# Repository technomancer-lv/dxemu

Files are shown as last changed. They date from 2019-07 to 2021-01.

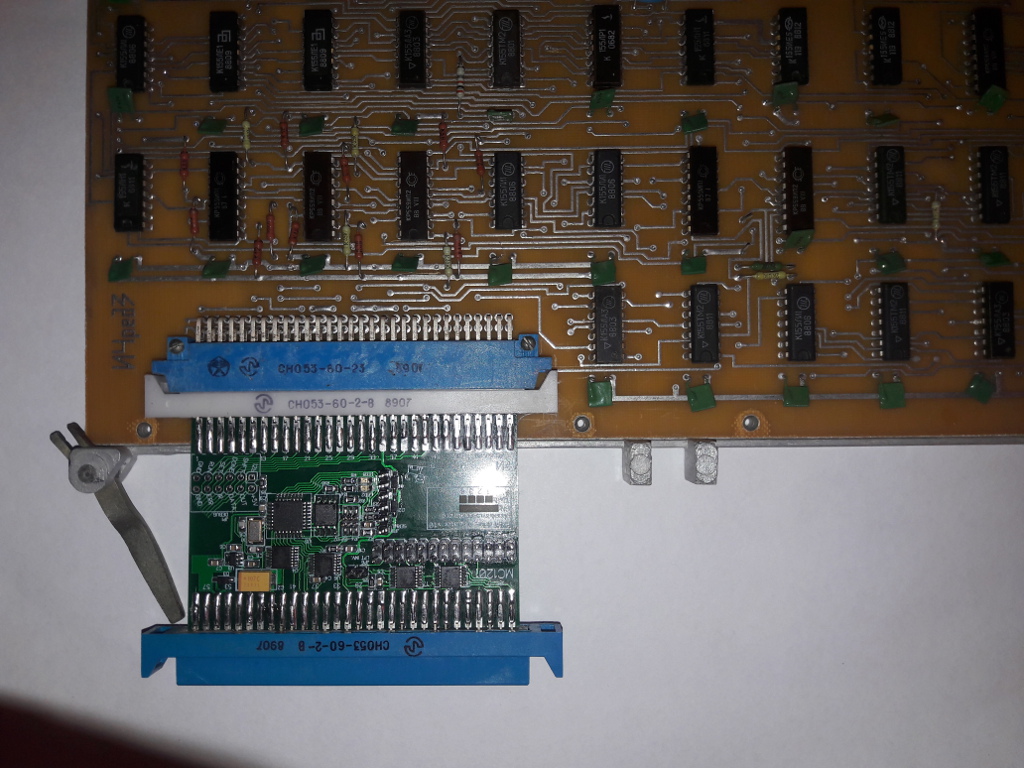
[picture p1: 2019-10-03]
pictures/6-dxemu-connected-i4.jpg

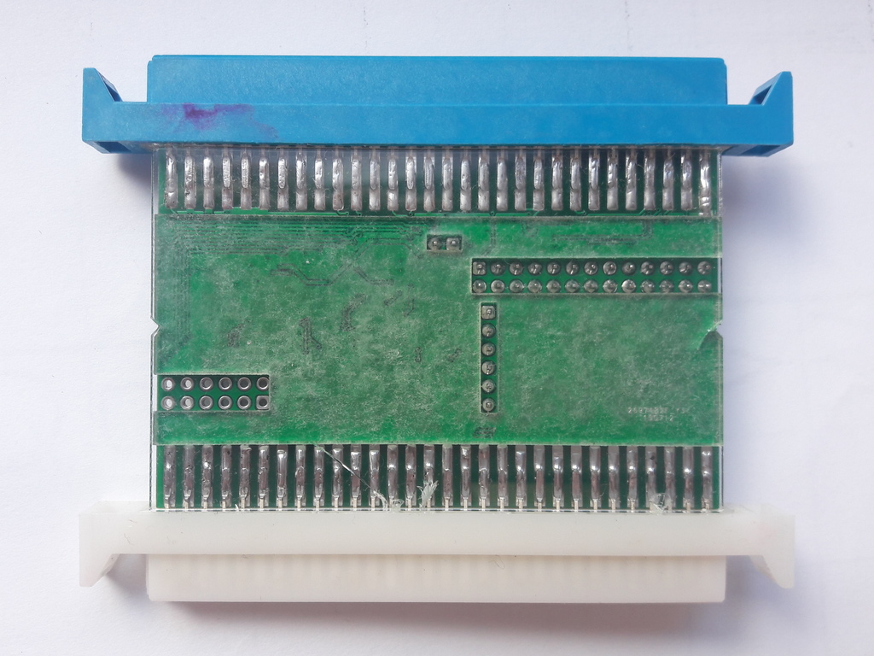
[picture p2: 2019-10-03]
pictures/4-dxemu-v1.0-bot.jpg

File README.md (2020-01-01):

### What's this project for?
This project is small and simple replacement for dual 8" floppy drive GMD-70 (ГМД-70) used with Soviet made PDP-11 compatible computers DVK (ДВК) and Electronica-60 (Электроника-60). Emulator is tested as working with MS1201.01, .02 (МС1201.01, .02) CPU boards with integrated controllers and with I4 (И4) standalone controller board. Will be tested with original PDP-11 RX01 controller card if I'll ever get one.

### What's the purpose of this?
There are several pros of this emulator:
- small size lets to install it directly into case of DVK-2M and Electronica-60.
- no need for enormous external 8" floppy drive what makes retro computer easier to demonstrate.
- it's possible to load floppy drive image over Arduino compatible TTL serial cable what makes it easier to exchange files with retro computer.
-  can be used to reliably boot computer and to initialise different boot media, for example, MX format 5" disks and MFM hard drives.
-  same connector that's used for floppy connection is also used for parallel printer connection. Centronics compatible connection to Epson dot-matrix printer is prototyped and tested.
- bottom side of the board is isolated, so there's no risk of damaging it if bottom side is shorted to ground.

cons:
- not as fast as I thought it will be because of flash memory 4K block erase only. It takes time to read-modify-write to change only 128-byte sector.
- computer board needs one small physical modification (shorted resistor) so it gets enough power from CPU board. Also, 5V power should be added to I4 board connector with short wire.

### What's the status of this project?
It emulates two floppy drives DX0: and DX1:. Floppy image upload and download works over Xmodem, it's tested with minicom on Linux and with TeraTerm on Windows. There's backup and restore functionality ready to be used. Printer port is working with Epson dot-matrix printer. Bootloader seems to be working fine. Emulator has to be tested on MS1201.01. Anyhow, RT-11 is booting stable, drives can be initialised, files can be read and written. Small batch is going to be made soon, it will be fully tested and will be put for sale.

### How it's made?
MCU program is written on native C language, it's compiled under linux CLI. Makefile includes several tweaks for automatic including of serial number and build number in final binary file. Should be easily switch it to any IDE or even as Arduino project. Board supports Arduino-like bootloader for easy software upgrade over serial connection. Also I had an idea about firmware upgrade over Xmodem protocol, but I've put lot of time into this, I'm a bit tired of this and at the moment it's working stable so I'm going to do some other projects while trying to sell few assembled emulators. Schematics and board are designed with P-CAD 2006. Yeah, I know. I'm an oldfart and pirate, but, hey, I'm grown to this CAD and while I can make anything I need with it, I'm still using it.

### How to boot it for first time?
1. **+5V power** should be connected to connector where emulator is connected. On MS1201.01 and .02 bord there's resistor R16 that's going from +5V to "ЛОГ1" signal on floppy/printer connector (pin 56). As this signal is not used, resistor can be shorted with short wire, so there's +5V on that pin.
On И4 controller board, +5V should be connected to unused pin 35 with short wire. See pictures for examples (pictures to be added soon).  
2. **Connect emulator** to prepared board. There are markings on board which side connector is for MS1201 and which for И4.
3. **Switch on your computer.** Bootable RT-11 floppy image should be already programmed into emulator.
4. **Give boot command:**\
    MS1201.01 - D0\
    MS1201.02 - B DX0\
    И4 - 177300G\
   Activity LED of drive 0 should start blinking and computer should boot RT-11.
5. **That's it!** Enjoy Your emulated RX01 floppy drive and play some original Tetris game. Drive 1 are not initialised by default, but you can do it easily from RT-11 with command **INI DX1:** and You'll have another 256KB to store Your data.

### Printer port.
MS1201 boards have floppy and printer signals connected to same connector. As an additional function, printer connections are connected to pin header that can be used to connect dot-matrix printer with standard Centronics connection. You can use flat cable to DB-25F adaptor that's removed from old PC compatible motherboard. Connect printer to this adaptor cable and You can print text files from RT-11 with command **COP TEXT.TXT LP0:**. This function is tested with two different Epson printers and one Centronics printer. Printer functionality is not affected in any way from onboard microcontroller.

### Built-in serial port.
Six pin header on board is Arduino pinout compatible TTL serial port. It can be used for firmware upgrade over Arduino compatible bootloader. Also, there is simple command-line interface, that can be used to upload and download floppy images, to locally backup and restore images and also to use debug and statistics functions. Baudrate for both bootloader and CLI is 115200. Emulator can be supplied standalone from serial connection.

### Console commands.
Commands are case insensitive. Available commands are:\
? (or any other unrecognised command) - help\
xs0 - send RX0 image over Xmodem\
xs1 - send RX1 image over Xmodem\
xr0 - receive RX0 image over Xmodem\
xr1 - receive RX1 image over Xmodem\
b0 - backup RX0 image\
b1 - backup RX1 image\
r0 - restore RX0 image from backup\
r1 - restore RX1 image from backup\
d0 - disable debug\
d1 - enable debug\
d2 - enable verbose debug\
v - show version\
s - statistics

#### Floppy image upload to emulator.
Floppy images can be uploaded to emulator using Xmodem protocol. First, You need to have floppy image file with correct size - 256256 bytes. Connect serial cable, be sure that command line works and execute command **XR0** or **XR1** depending if You want to upload image of drive 0 or 1. After that, start image upload on your terminal emulator using Xmodem protocol and see if it uploads correctly. While uploading, image is copied to temporary area, so if upload fails, floppy image stays unchanged.

#### Floppy image download from emulator.
Floppy image can also be downloaded from emulator. It's started with command **XS0** or **XS1** and after that you should give receive command to your terminal emulator and see if it's downloading correctly. You'll get 256256 bytes large floppy image file that can be stored for future use, shared with other enthusiasts, written to real 8" floppy drive or loaded into PDP-11 emulator.

#### Backup and restore functions.
Sometimes while you're messing around with old hardware, you know that you can mess things up. In this case, you can accidentally erase floppy image, bake floppy unbootable or do some other stupid things. To save you from that, there's image backup and restore commmands. If you have good working floppy image, you can execute command **B0** or **B1** depending on which drive you would like to backup and image of that drive will be copied to backup area of Flash memory. If you mess something up, anytime you can execute **R0** or **R1** commands to restore previous contents of corresponding floppy drive. 0 and 1 drive image backup are stored in different locations, so both drives can be backuped simultaneously.

#### Debug.
To see if your computer is exchanging data with floppy drive, you can use debug functions. Command **D1** turns on simple debug. It shows command numbers issued by computer, together with track and sector numbers with commands that reads data from floppy or writes to it. Command **D2** turns on verbose debug that also prints out data that are stored in emulator buffer or are read from it. Verbose debug mode is not recommended to be used, because of large data amount that has to be send over serial line. It slows things down and caused me some other problems. Maybe this debug should be made in different way. Use on your own risk.
Debug function is turned off with command **D0**.

#### Version.
Command **V** prints out serial number, bootloader version and firmware version. Firmware can be upgraded and so will change firmware number. Bootloader version and serial number are both stored in bootloader section, so these are unaffected by firmware changes.

#### Statistics.
Command **S** prints out simple statistics - board uptime, sectors read and written on both disks.

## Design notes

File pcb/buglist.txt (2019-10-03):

1. (fixed) Two RefDes on PCB are swapped
2. (fixed) Pin 2 of JP5 should be connected to GND

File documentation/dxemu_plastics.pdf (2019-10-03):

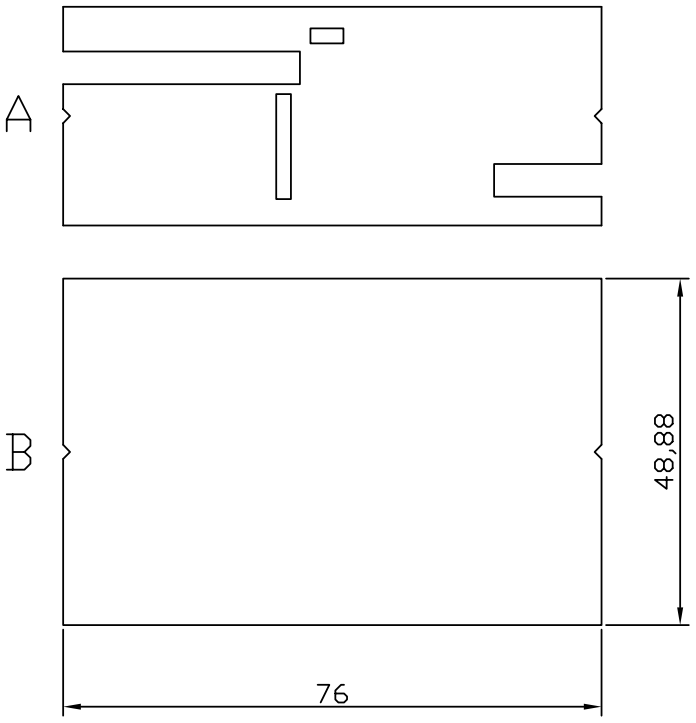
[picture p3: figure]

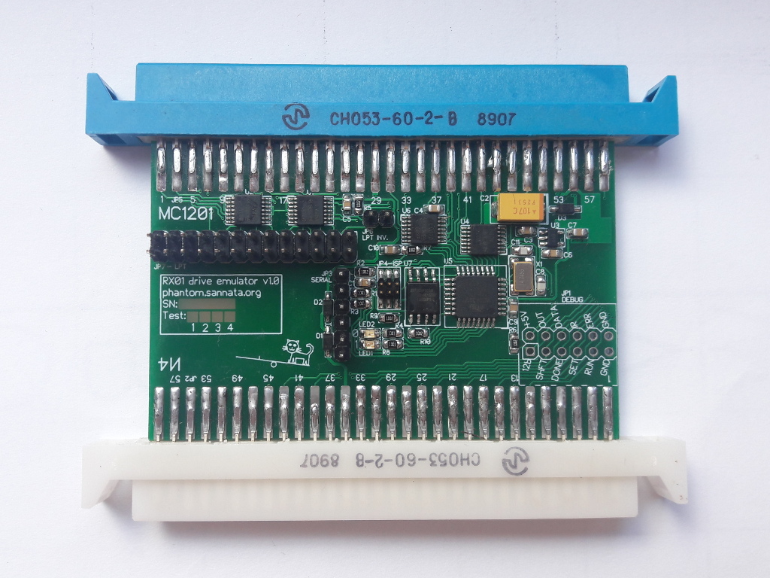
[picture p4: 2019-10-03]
pictures/3-dxemu-v1.0-top.jpg

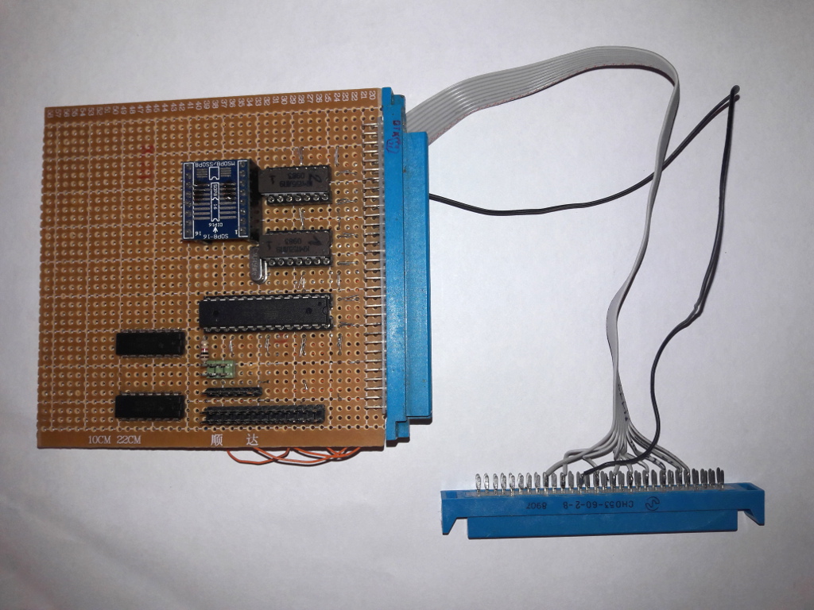
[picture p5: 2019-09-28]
pictures/1-dxemu-prototype-top.jpg

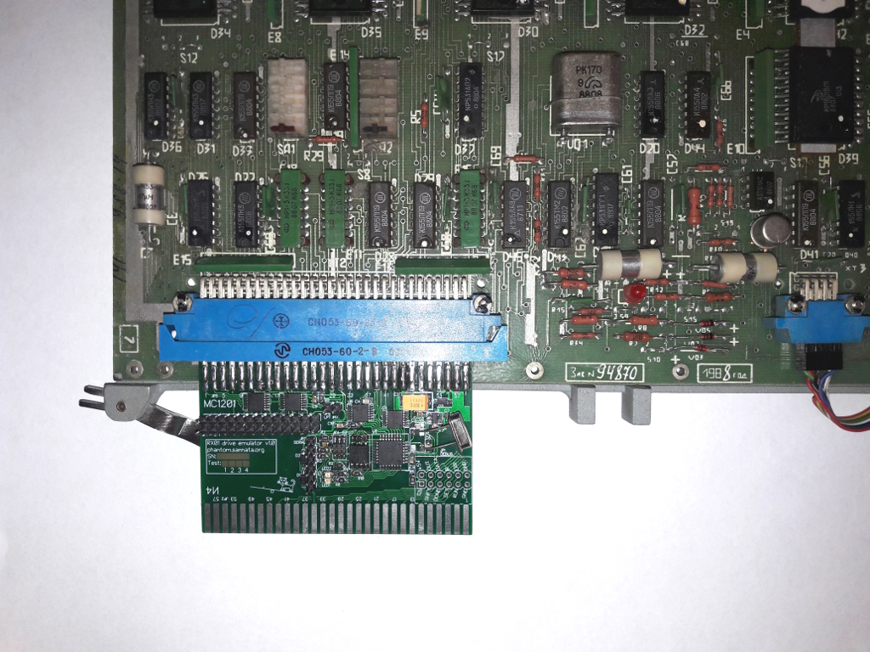
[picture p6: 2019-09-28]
pictures/5-dxemu-connected-ms1201.02.jpg

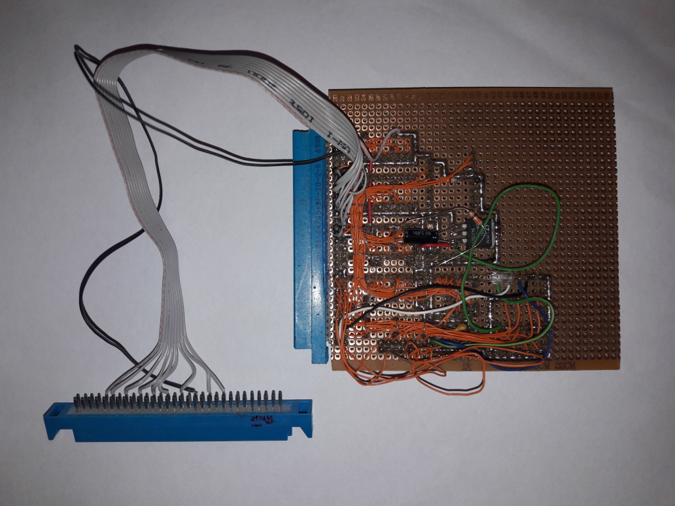
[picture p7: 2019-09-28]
pictures/2-dxemu-prototype-bot.jpg

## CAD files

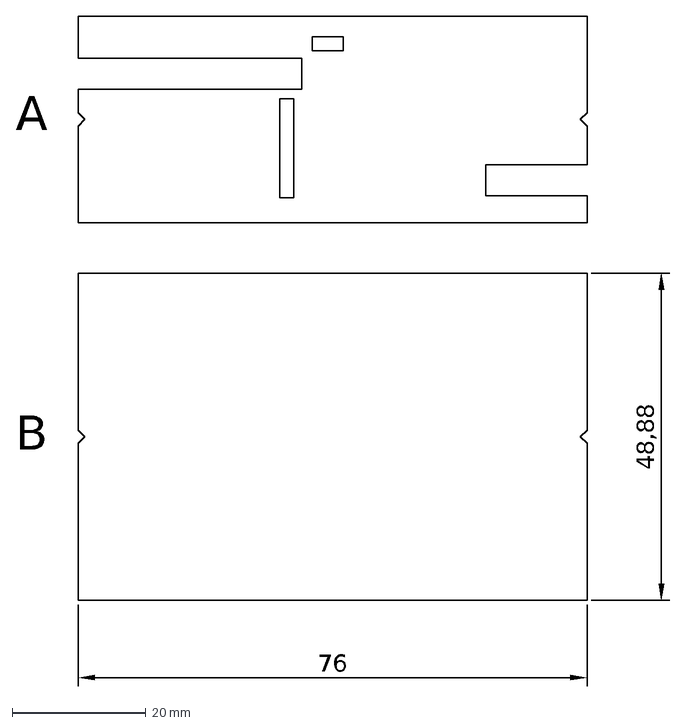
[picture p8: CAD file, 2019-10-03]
cad/dxemu_plastics.dxf
A
76
48,88
B

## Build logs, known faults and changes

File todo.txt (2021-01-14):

Add explanatory pictures to readme.md
Add proper Xmodem up/download instructions

Prog:
  Try to solve the restaart issue trying to find if the orphaned INT is the problem
  Smaller todo steps are marked in the beginning and all over program source
  Maybe firmware update over Xmodem? Flash capacity allows this
  _Simple statistics - sectors wrote, sectors read, system uptime, errors
  _Make automated test script for testing backup, restore and file transfer functions
  Add drive number to sector related debug functions
  Programmer out of sync - test on other computers too
  Optimise:
    Make one text output function for strings stored in Flash
  
Mechanical:
  Fix plastics part width issue
  Assign part numbers to plastic parts
  
Electrical:
  Test with real PDP-11 RX01 controller
  
PCB:
  If there will be demand, PCB v 1.1 can be made with fixes:
    LPT signal issue - connect pin2 to GND
    Two component RefDes are swapped
    Maybe remove programming connector
    PCB too wide to fit behind DVK front panel with both connectors soldered
    Maybe remove debug connector and 12b signal
    Edge connector pad length can be reduced, thus making board more narrow
    LPT INV can be controlled from MCU or can be removed at all
      If two XOR IC's are replaced by two invertor IC's, one of 7407's can be removed
    Use smaller components

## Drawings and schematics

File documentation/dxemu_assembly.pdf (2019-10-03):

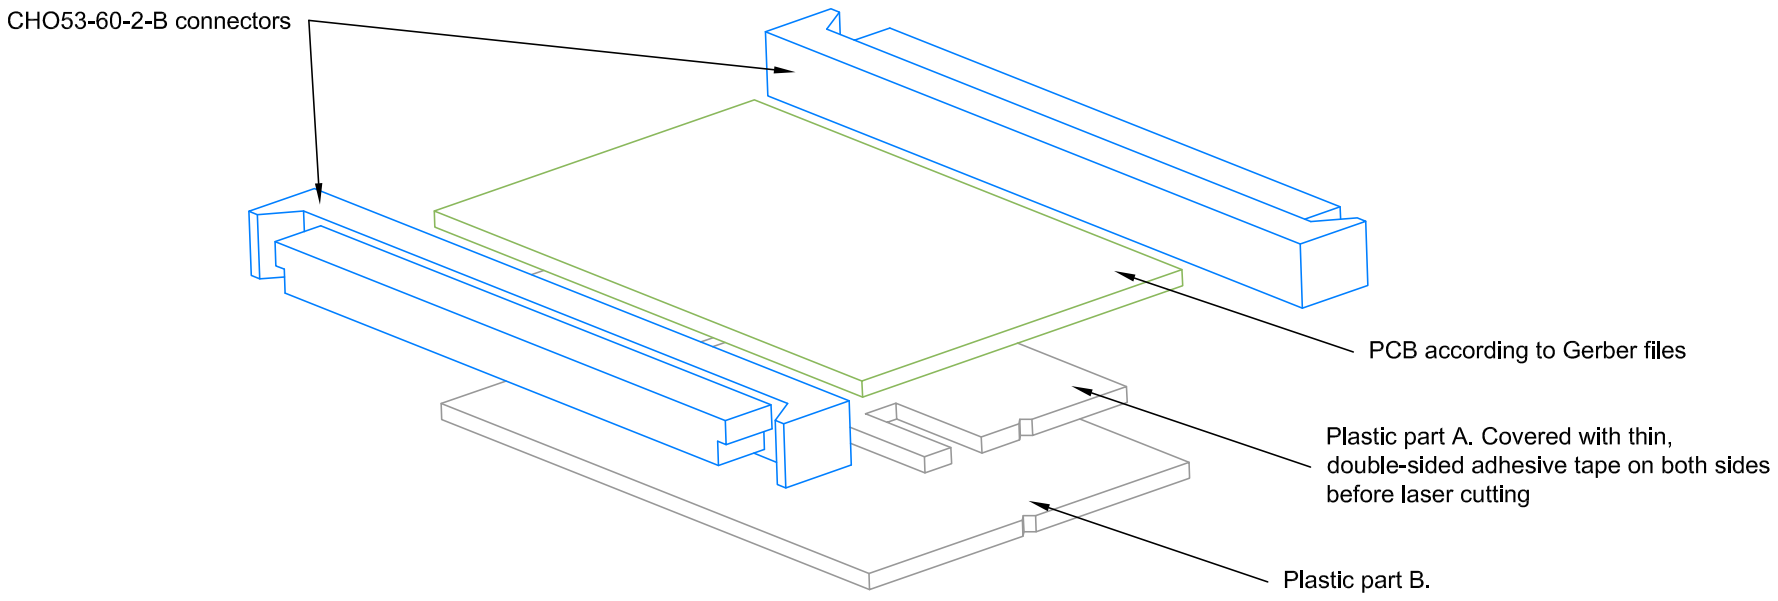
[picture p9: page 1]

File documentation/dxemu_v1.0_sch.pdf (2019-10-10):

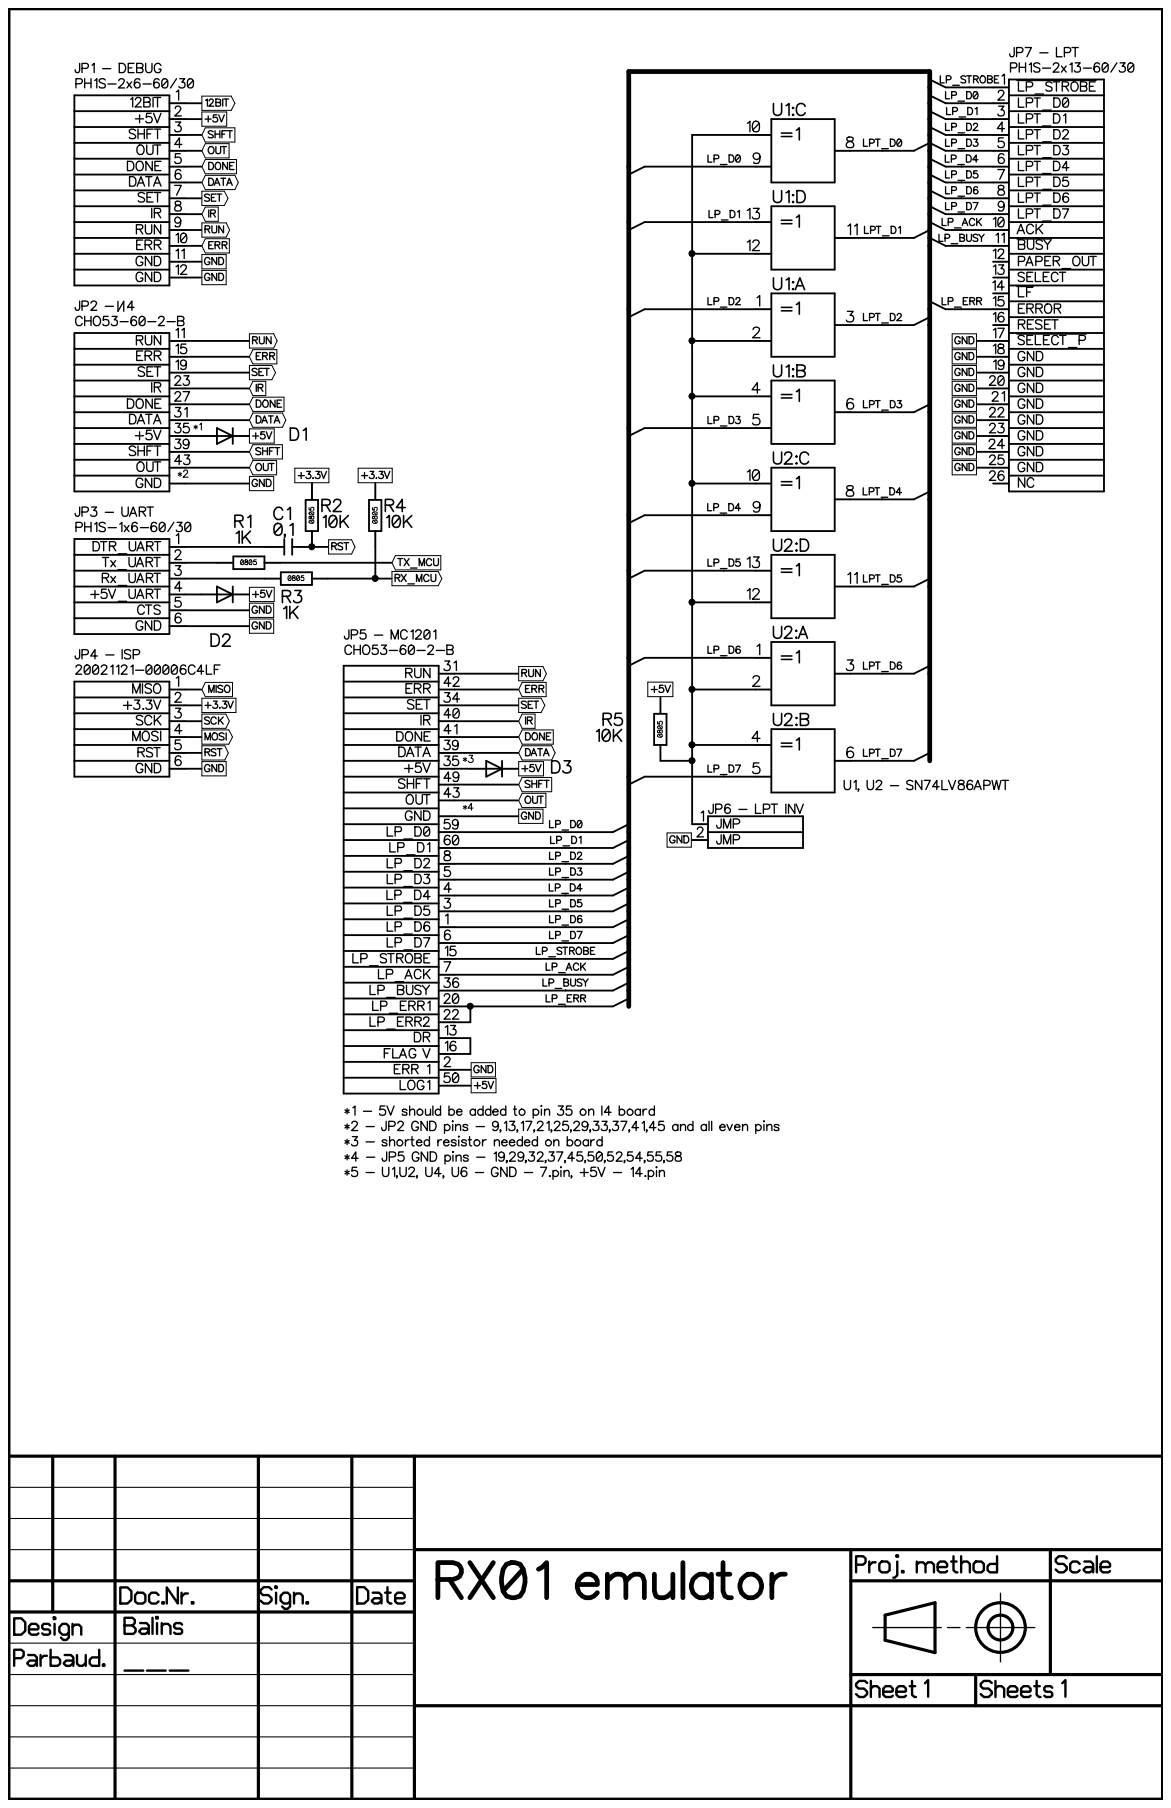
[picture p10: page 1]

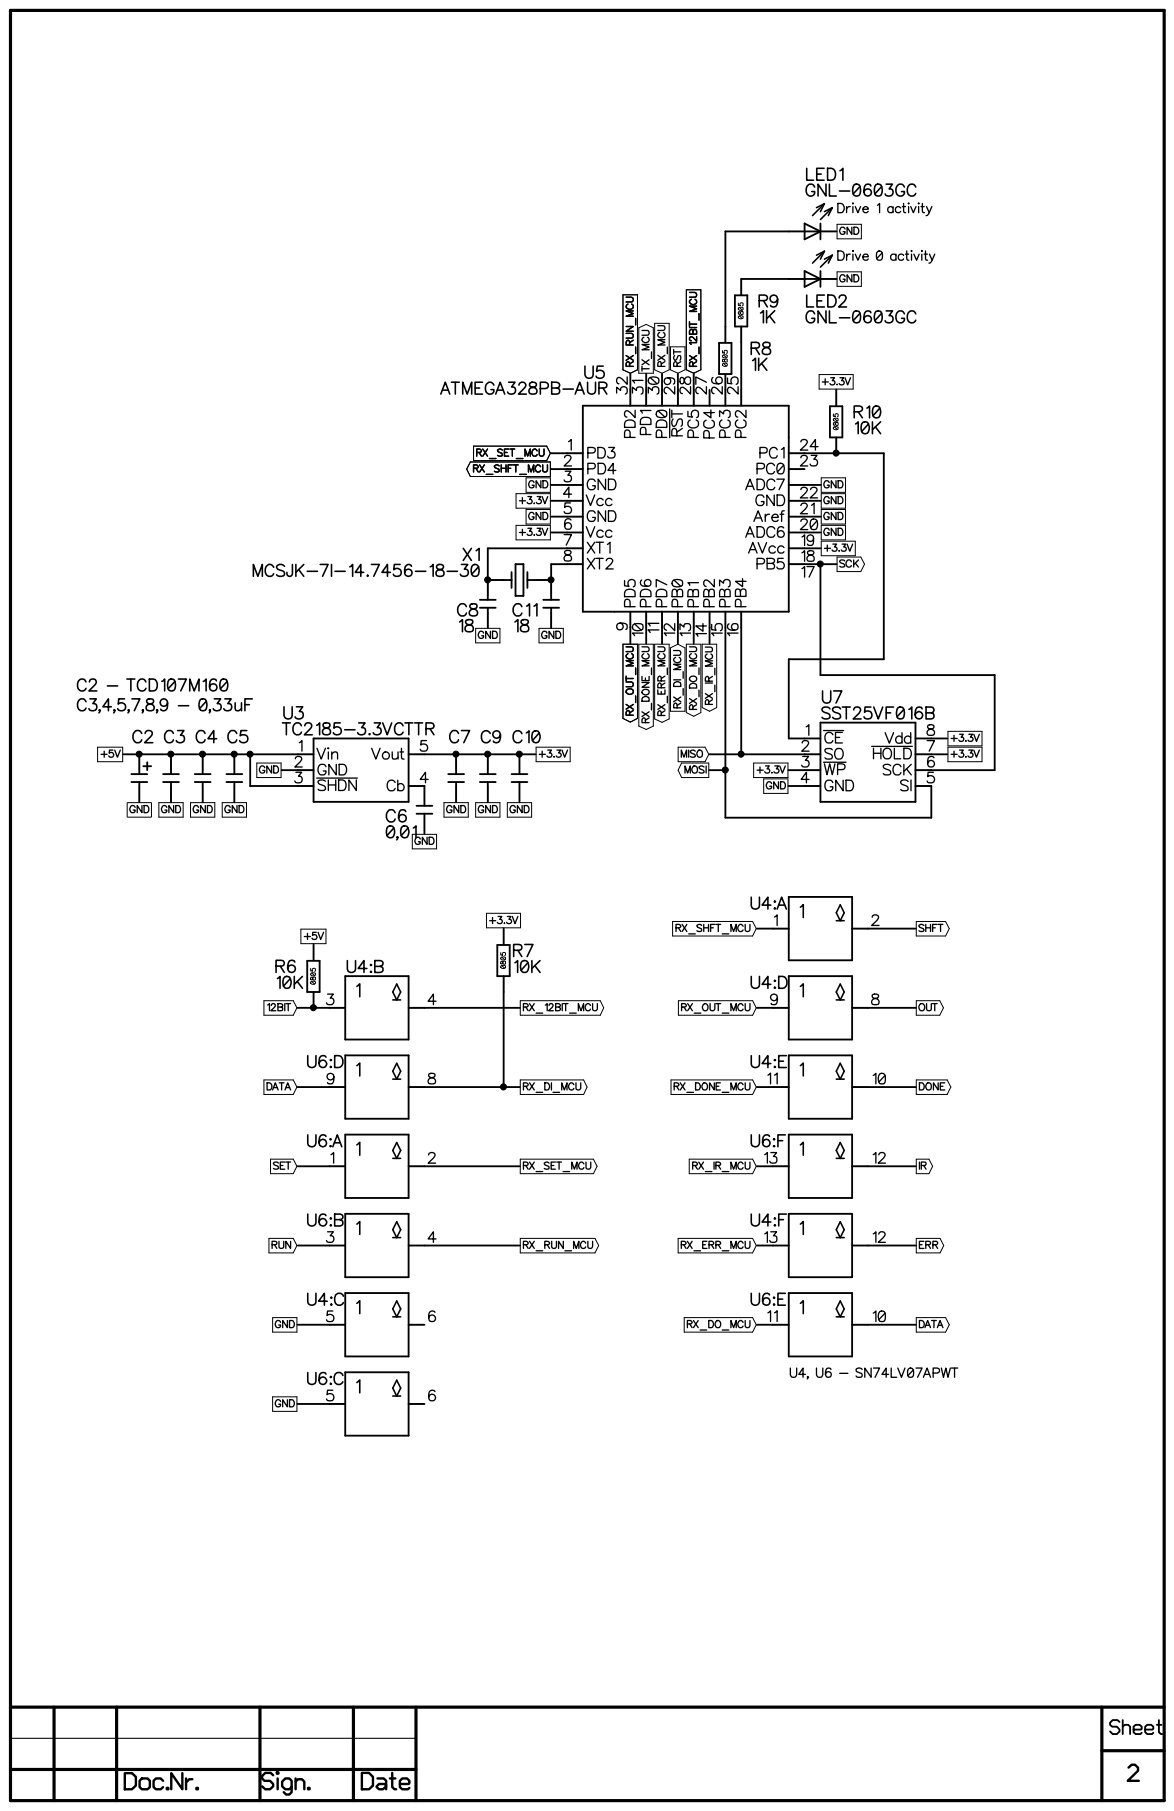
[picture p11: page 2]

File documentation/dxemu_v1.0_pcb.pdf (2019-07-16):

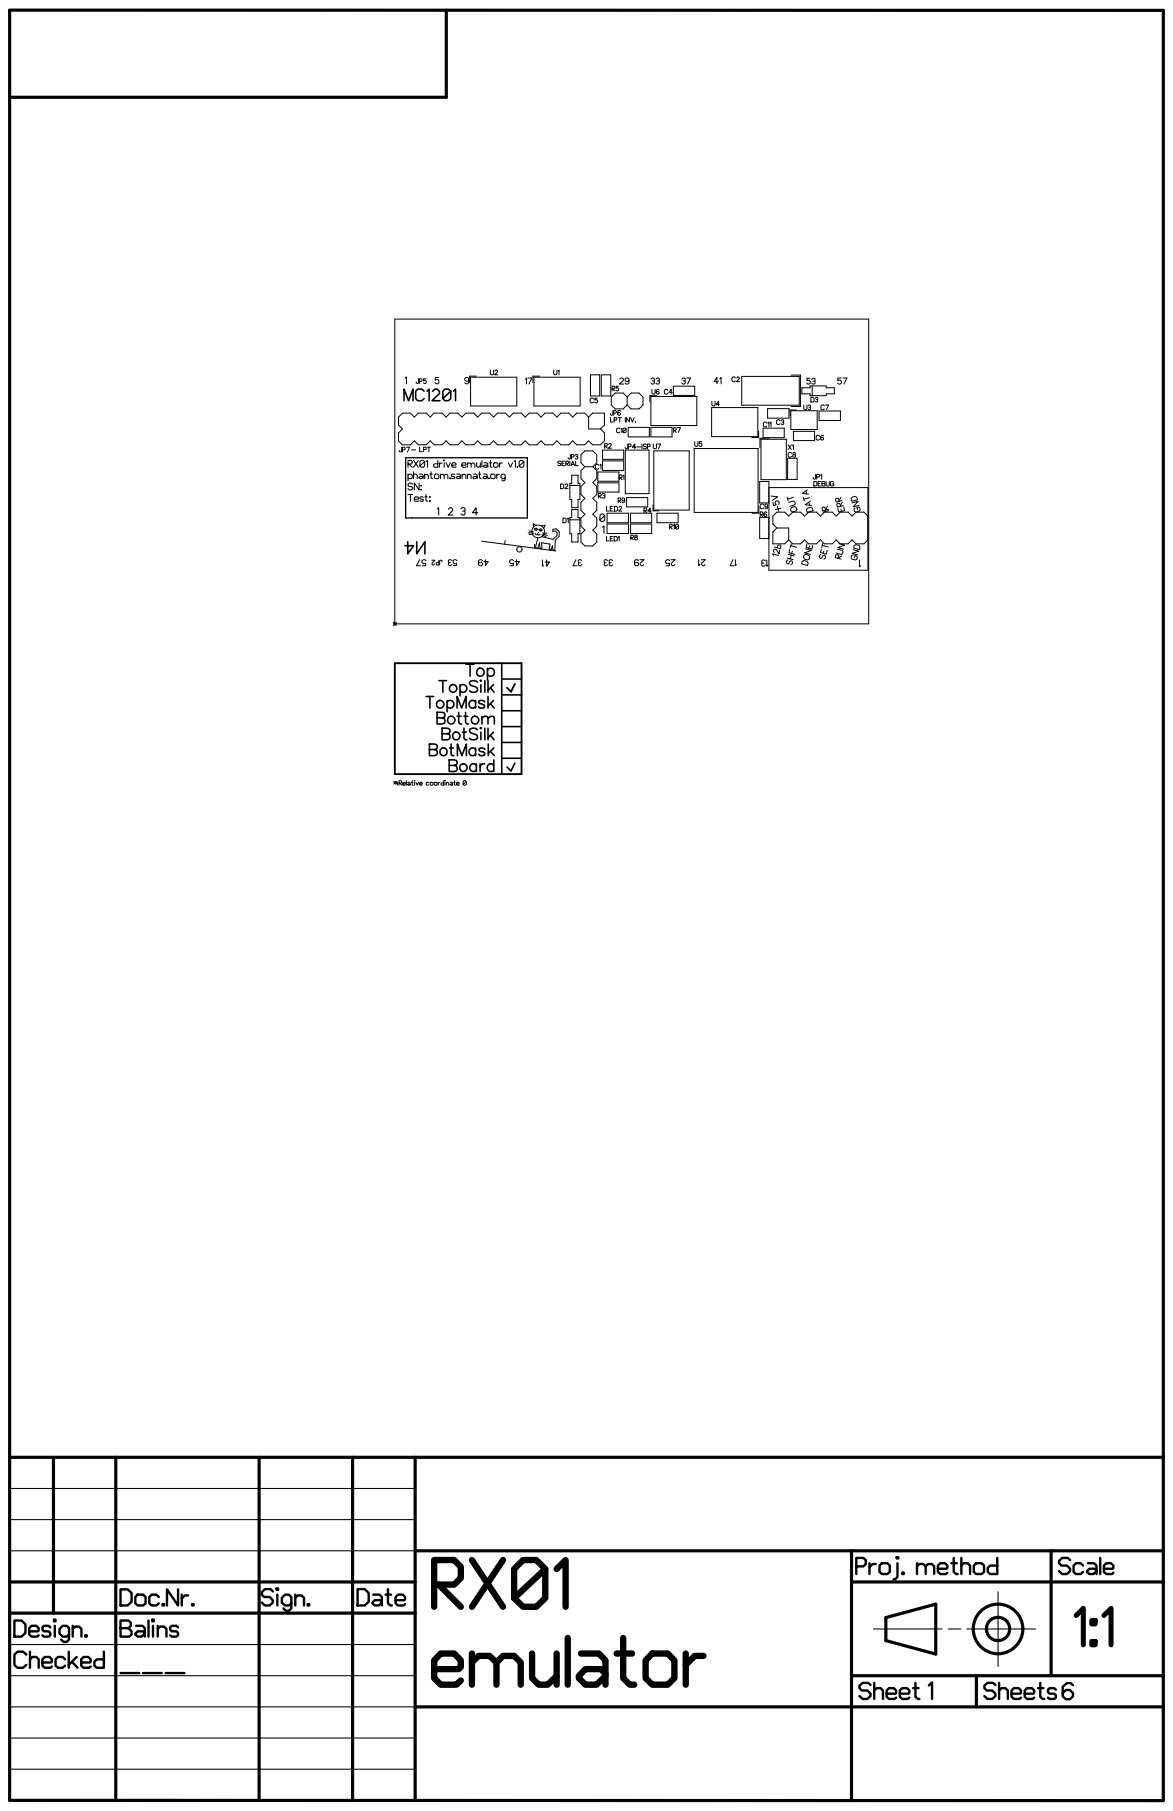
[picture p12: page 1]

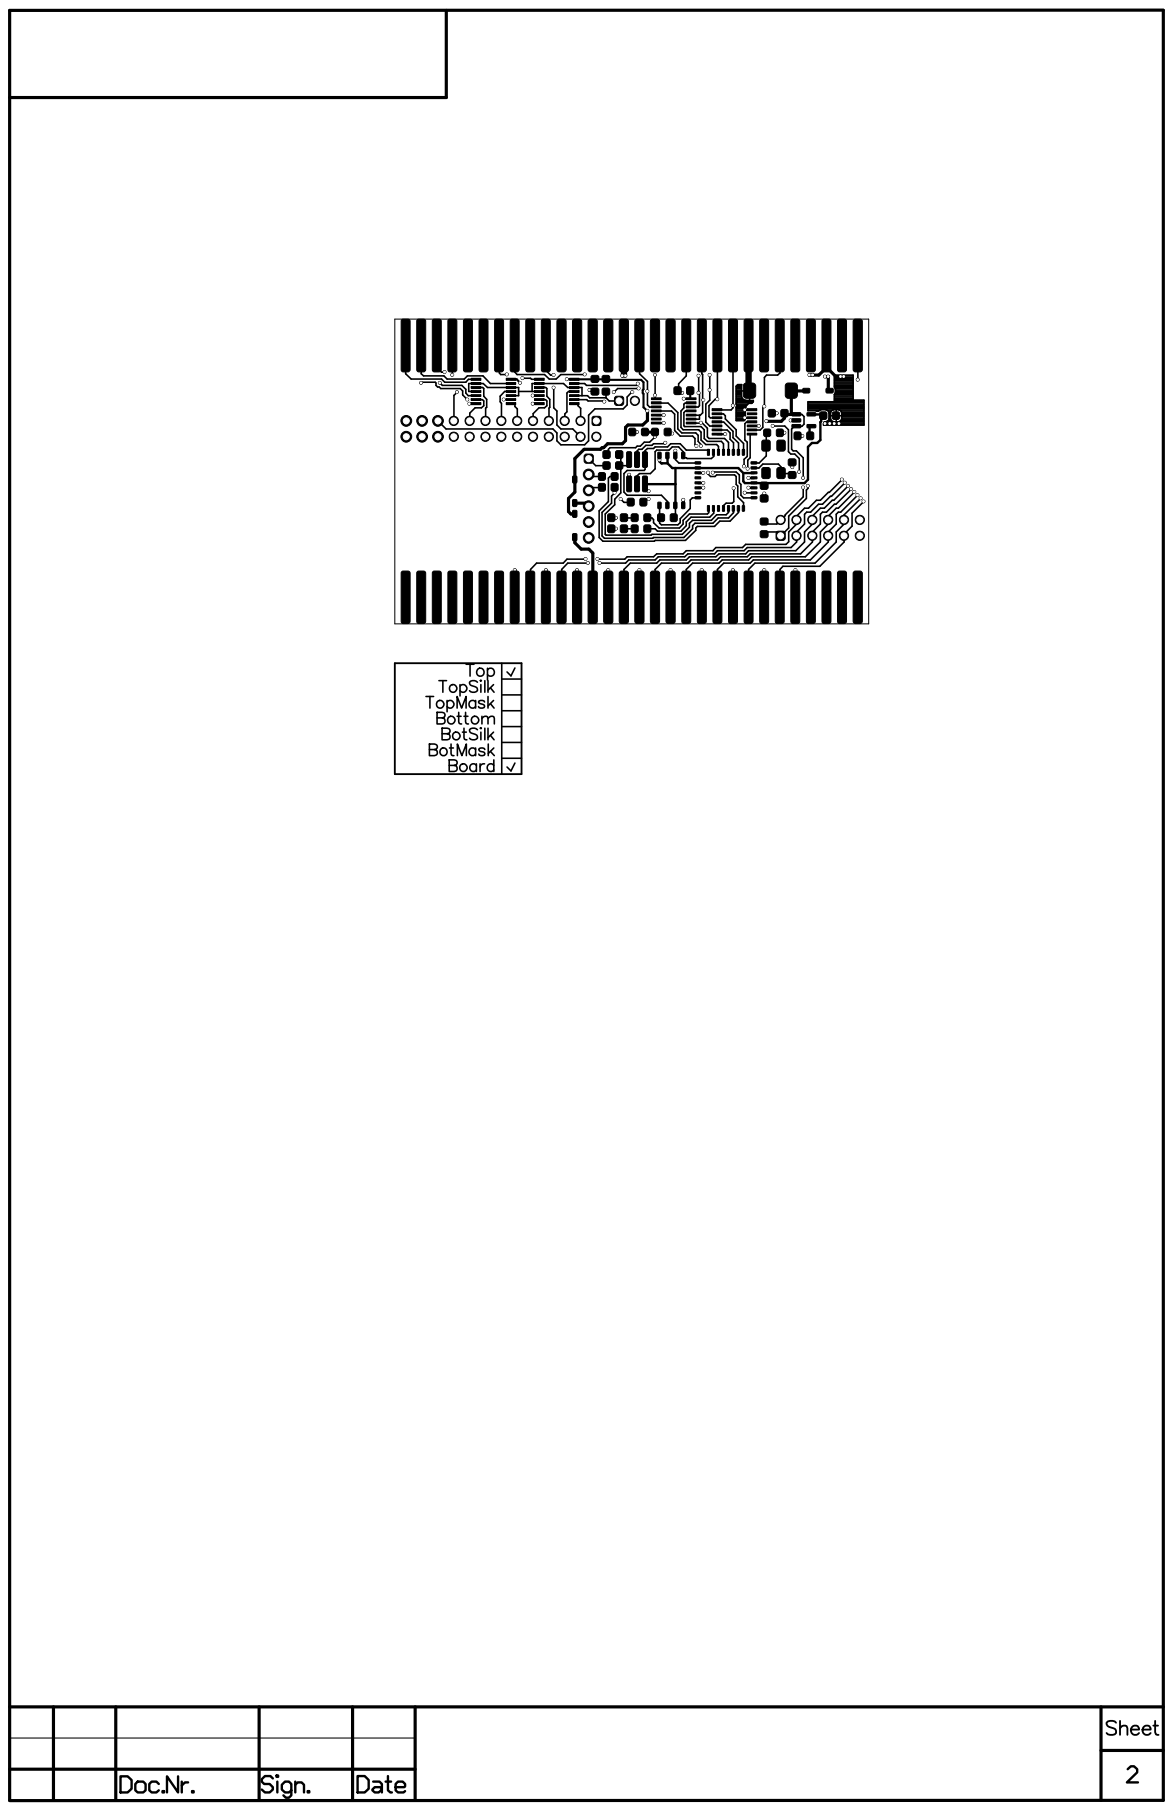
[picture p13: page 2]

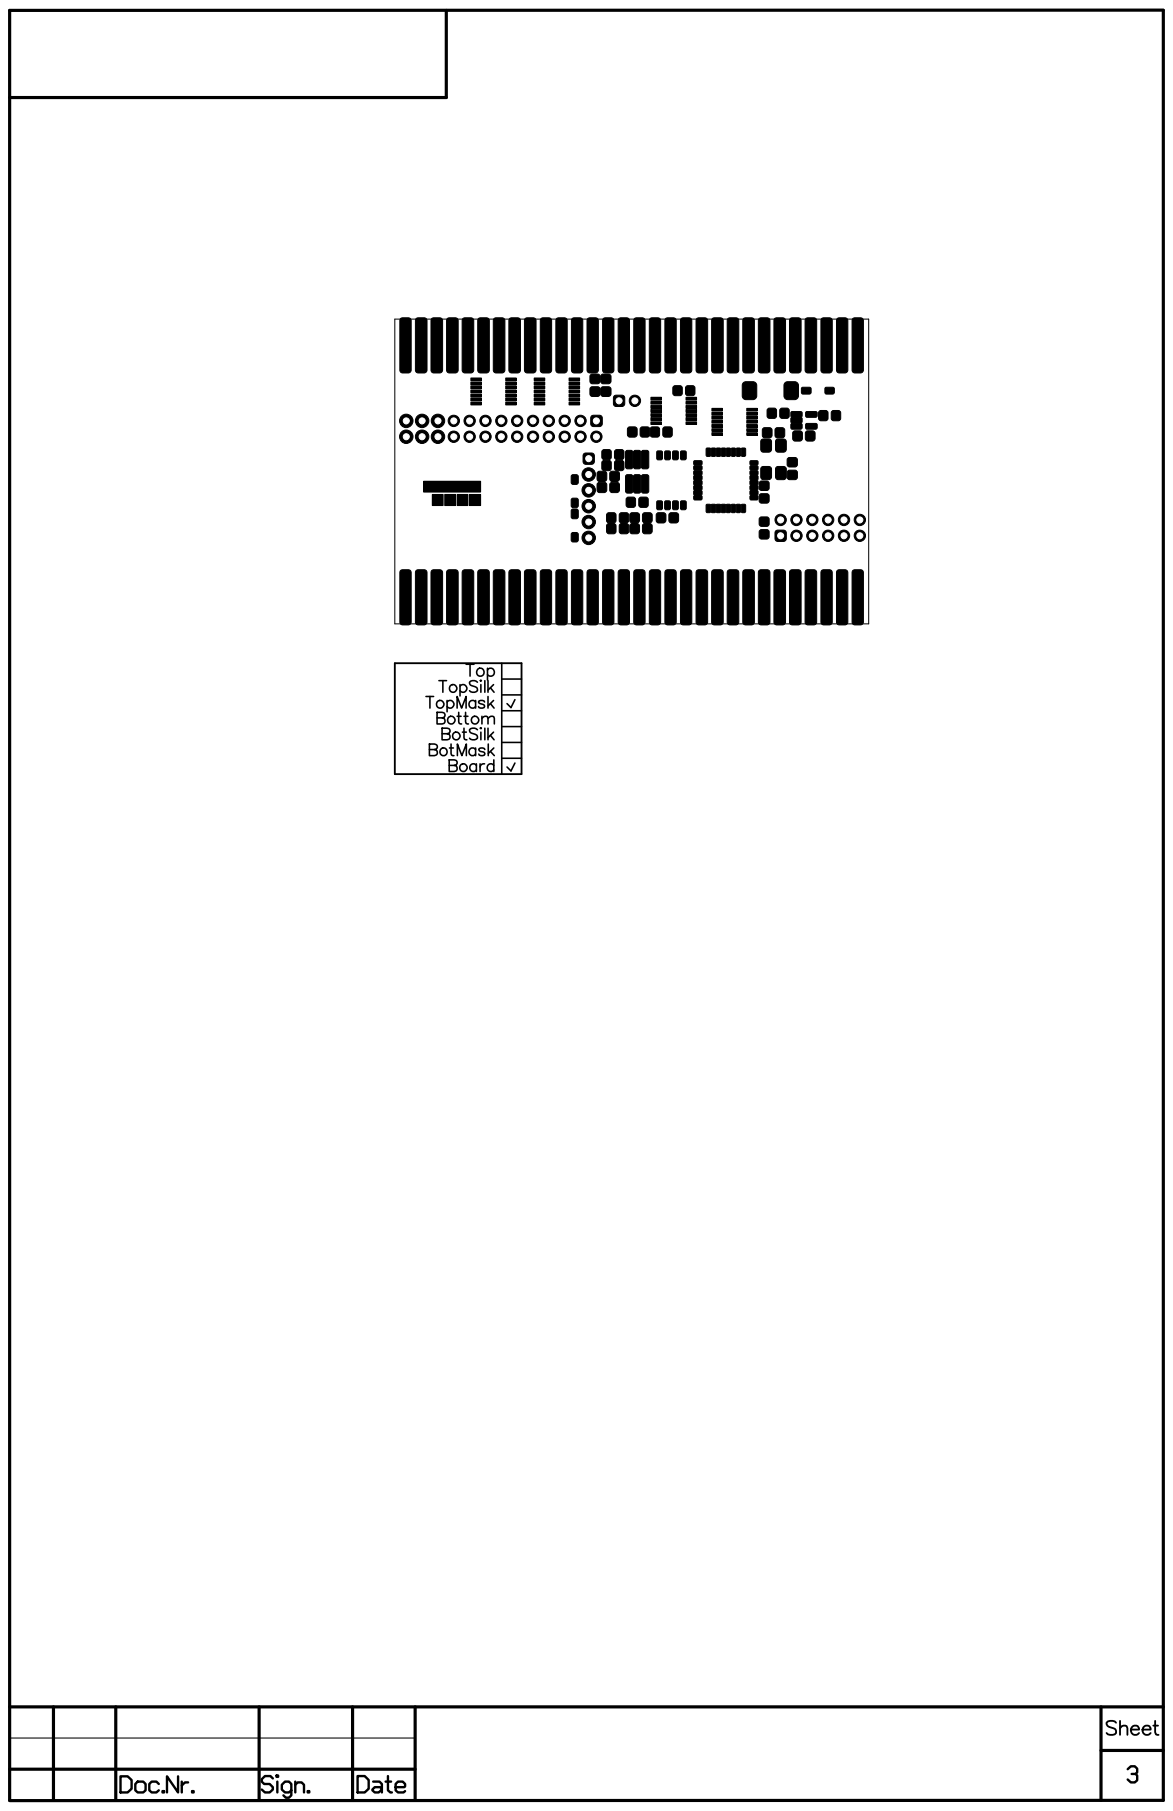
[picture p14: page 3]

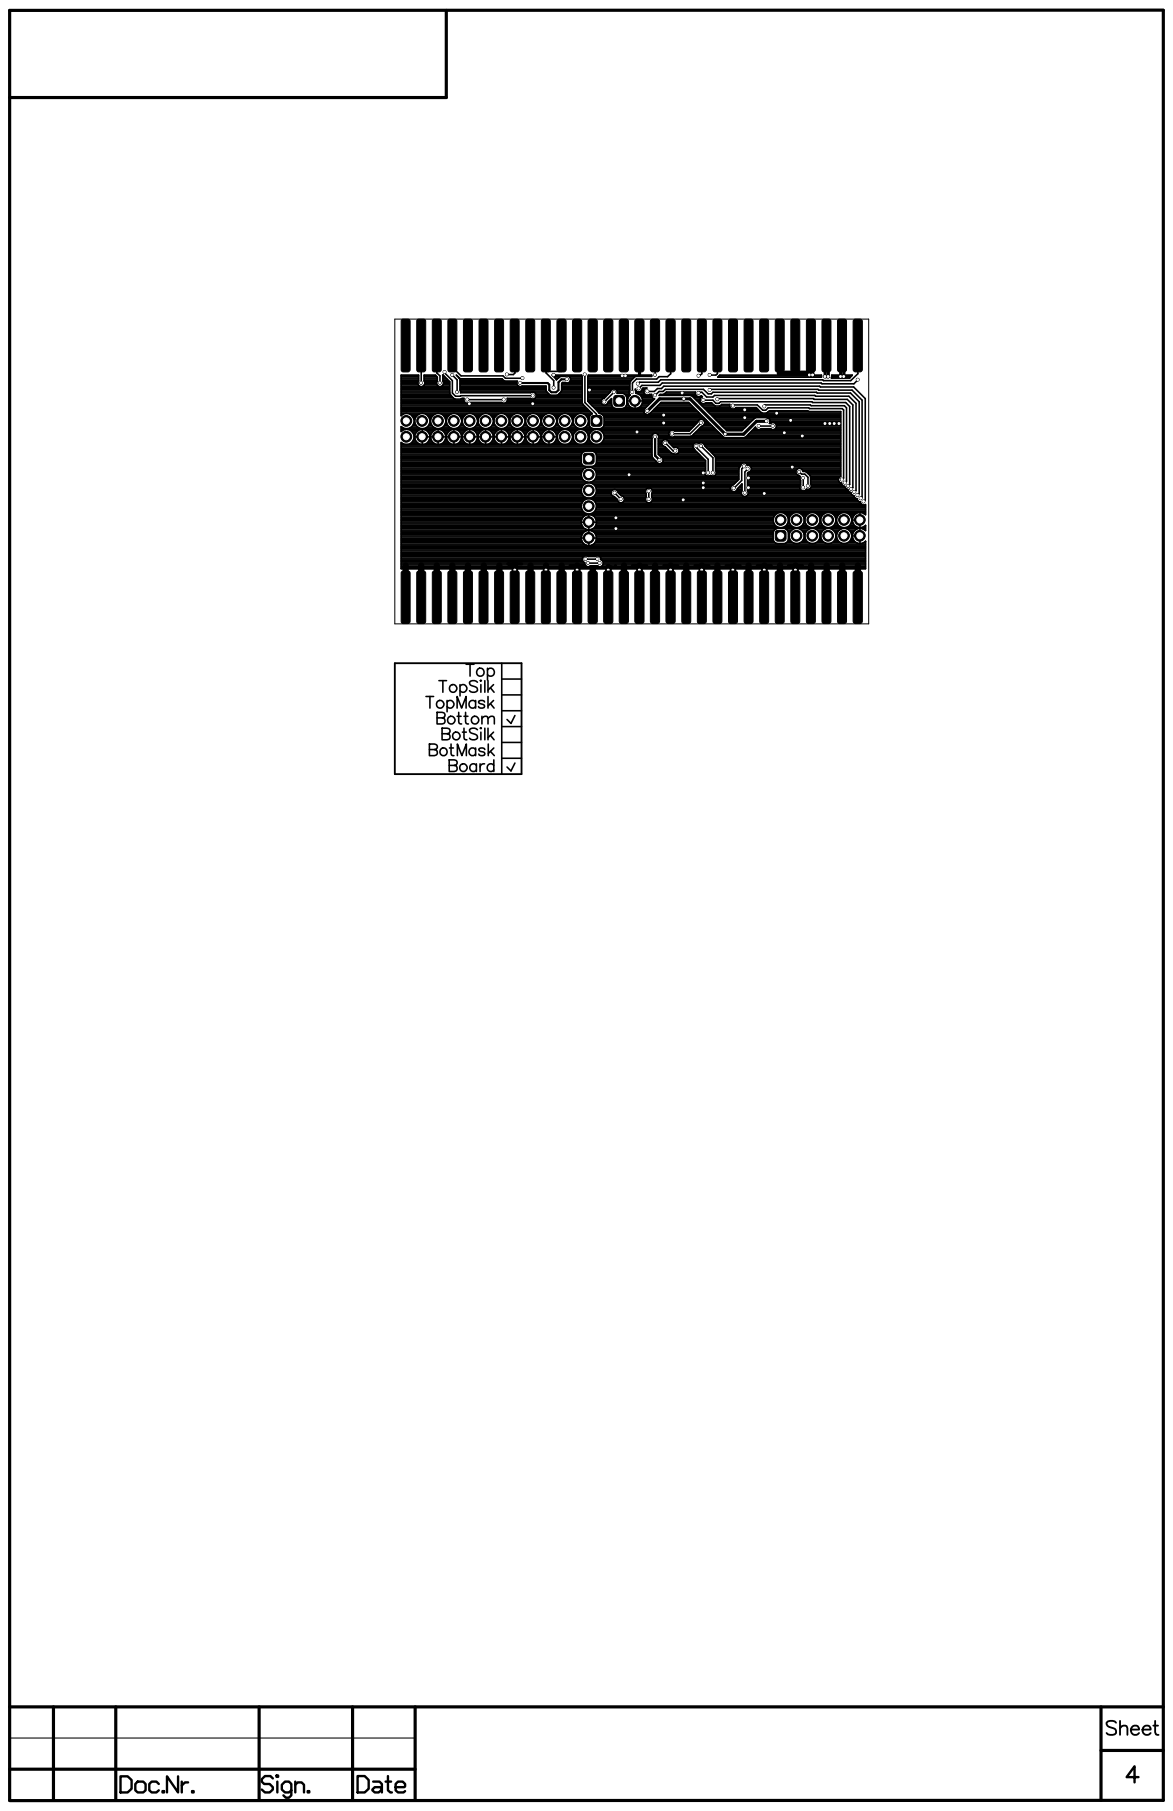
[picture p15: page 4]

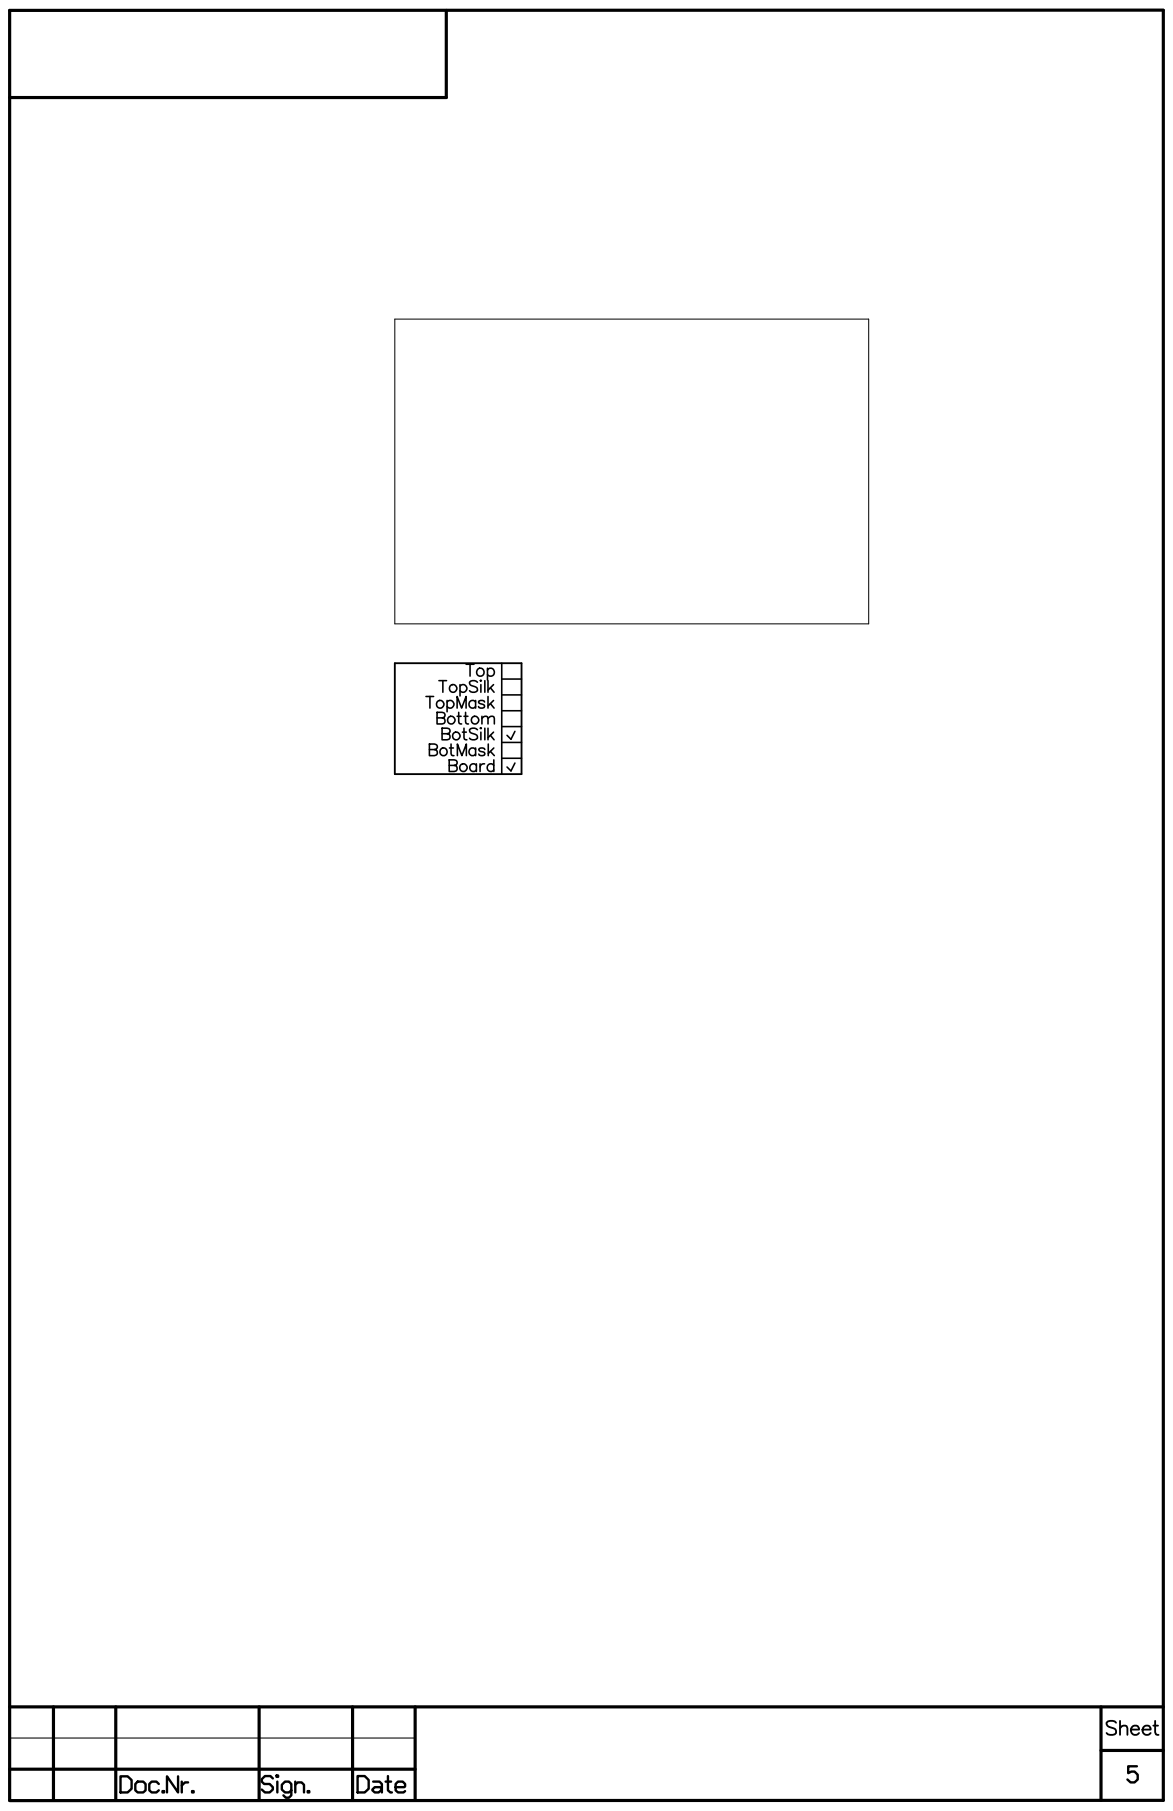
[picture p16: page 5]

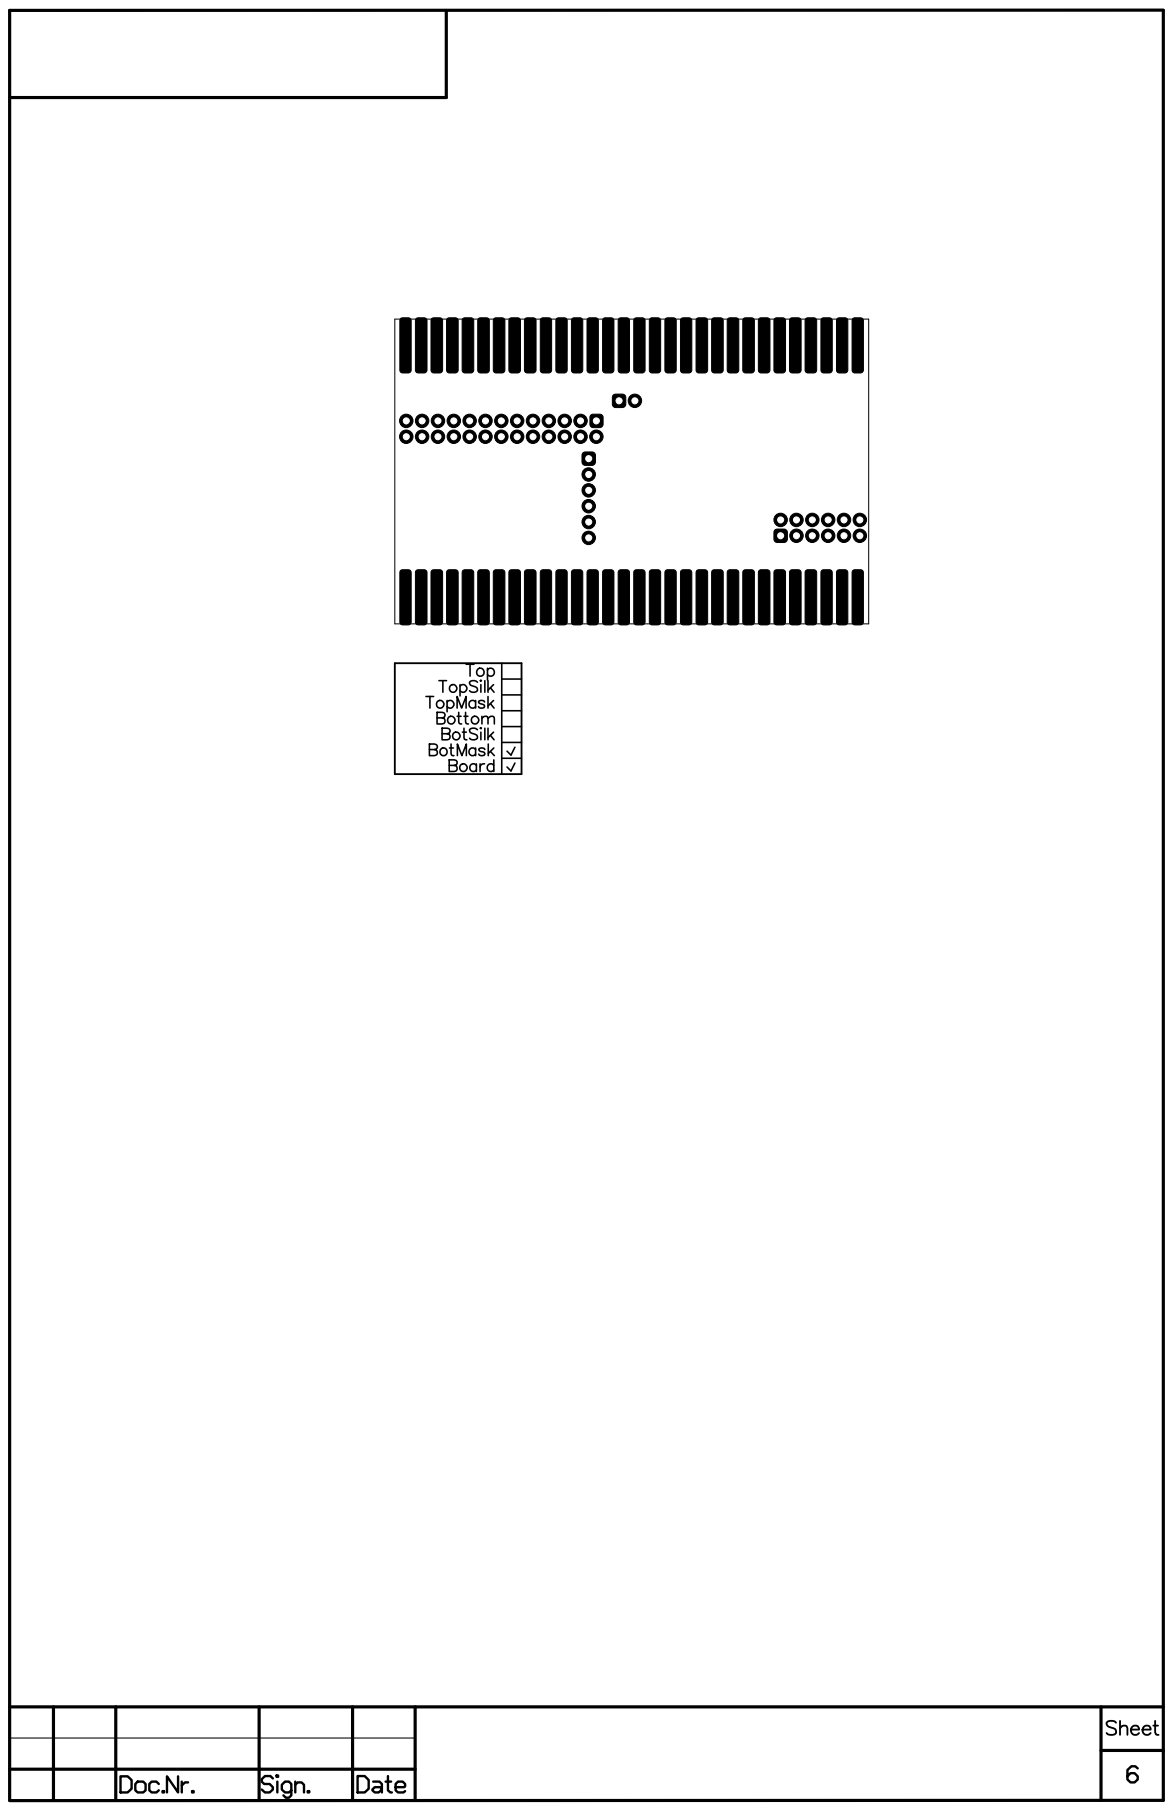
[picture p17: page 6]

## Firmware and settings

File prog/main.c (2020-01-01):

/*	Program for emulating PDP-11 RX01 floppy disk drive
*
*	CPU:	ATMega328PB
*	F_CLK:	14,7456MHz
*
*	Fuses:
*
*	Pin naming is taken from KR1801VP1-033 interface pin naming.
*	Data is shifted MSB first
*	Command and both addresses are 9-bit long with parity bit as LSB
*
*	TODO:	Write marked sectors
*		Add 12bit compatibility?
*		Parity check (in progress)
*		Function time-outs
*		Divide code into separate files
*		Statistics - error count
*
*/

#include <avr/io.h>
#include <util/delay.h>
#include <avr/interrupt.h>
#include <avr/pgmspace.h>
#include "avr_uart_fifo.h"

//DX drive IO pin init
//"Signal name in russian" (controller pin name) (I/O type)
//"Nach. ustanovka" (SET) (IN)
#define	DxSetPort	PORTD
#define	DxSetIn		PIND
#define	DxSetDdr	DDRD
#define	DxSetPin	3

//"Pusk" (RUN) (IN)
#define	DxRunPort	PORTD
#define	DxRunIn		PIND
#define	DxRunDdr	DDRD
#define	DxRunPin	2

//Dannie (DI) (I)
#define	DxDiPort	PORTB
#define	DxDiIn		PINB
#define	DxDiDdr		DDRB
#define	DxDiPin		0

//Dannie (DO) (O)
#define	DxDoPort	PORTB
#define	DxDoIn		PINB
#define	DxDoDdr		DDRB
#define	DxDoPin		1

//Treb. peredachi (IR) (OUT)
#define	DxIrPort	PORTB
#define	DxIrIn		PINB
#define	DxIrDdr		DDRB
#define	DxIrPin		2

//Zaversheno (DONE) (OUT)
#define	DxDonePort	PORTD
#define	DxDoneIn	PIND
#define	DxDoneDdr	DDRD
#define	DxDonePin	6

//Vivod (OUT) (OUT)
#define	DxOutPort	PORTD
#define	DxOutIn		PIND
#define	DxOutDdr	DDRD
#define	DxOutPin	5

//Oshibka (ERR) (OUT)
#define	DxErrPort	PORTD
#define	DxErrIn		PIND
#define	DxErrDdr	DDRD
#define	DxErrPin	7

//Sdvig (SHFT) (OUT)
#define	DxShftPort	PORTD
#define	DxShftIn	PIND
#define	DxShftDdr	DDRD
#define	DxShftPin	4

//TODO - add 12bit input pin and functionality
//so this would be compatible with ... what?
//12bit (IN)

#define	Dx12bitPort	PORTC
#define	Dx12bitIn	PINC
#define	Dx12bitDdr	DDRC
#define	Dx12bitPin	5

//UART
//Tx
#define	UartTxPort	PORTD
#define	UartTxIn	PIND
#define	UartTxDdr	DDRD
#define	UartTxPin	1

//Rx
#define	UartRxPort	PORTD
#define	UartRxIn	PIND
#define	UartRxDdr	DDRD
#define	UartRxPin	0

//SPI
//CE (software controlled)
#define	SpiCePort	PORTC
#define	SpiCeIn		PINC
#define	SpiCeDdr	DDRC
#define	SpiCePin	1

//MISO
#define	SpiMisoPort	PORTB
#define	SpiMisoIn	PINB
#define	SpiMisoDdr	DDRB
#define	SpiMisoPin	4

//MOSI
#define	SpiMosiPort	PORTB
#define	SpiMosiIn	PINB
#define	SpiMosiDdr	DDRB
#define	SpiMosiPin	3

//SCK
#define	SpiSckPort	PORTB
#define	SpiSckIn	PINB
#define	SpiSckDdr	DDRB
#define	SpiSckPin	5

//Activity LED
#define	ActLedPort	PORTC
#define	ActLedIn	PINC
#define	ActLedDdr	DDRC
#define	ActLed0Pin	2
#define	ActLed1Pin	3

//Memory regions
#define	Dx0MemStart	0x000000
#define	CopyMemStart	0x040000
#define	Dx1MemStart	0x080000
#define	XmodemMemStart	0x0C0000
#define	Dx0BackupStart	0x100000
#define	Dx1BackupStart	0x180000

//TODO - change all mem offsets with these defines

//Welcome text, saved in program memory
unsigned char const StartupText[] PROGMEM="\r\n-----\r\nRX01 drive emulator for PDP-11 compatible computers.\r\nTested with MC1201.01, MC1201.02 and I4 boards.\r\nCreated by Technomancer\r\nphantom.sannata.ru";

//Variables
unsigned char	DxDriveSelected=0;	//Variable that holds selected drive number
					//0 - DX0
					//1 - DX1

unsigned char	CopyArray[128];		//Tempraroy data buffer array, used for data transfer over Xmodem
					//and data copying between data blocks

unsigned char 	DxArray[128];		//DX data buffer array, 128 bytes
unsigned char	DxArrayPointer=0;	//Pointer for saving and reading data from array
unsigned char	SecAddr=0;		//Sector address received from controller
unsigned char	TrackAddr=0;		//Track address received from controller

unsigned char	DxCommand=0xFF;		//DX command received from controller. Used in state machine
#define	NoCommand	0xFF		//If no command is being executed at the moment, DxCommand=0xFF

unsigned char	DxState=0;			//State machine state variable
#define	IdleState		0		//Idle state - no command are being executed
#define	SecAddrWaitState	1		//Waits for sector address (Commands 2,3,6)
#define	TrackAddrWaitState	2		//Waits for track address (Commands 2,3,6)
#define	FillBufferState		3
#define	ReadBufferState		4

unsigned char	DxStatusReg=0b10000100;
#define	DxParityErrorBit	1
#define	DxMarkedSectorActionBit	6

unsigned char	DxErrorReg=0;

unsigned char	TempBlockNum=0;

unsigned char	SystemStatus=0;
#define	DebugOn		0
#define	DebugVerbose	1

unsigned char 	DxTimeout=0;
unsigned int 	XmodemTimeout=0;

unsigned int	DxSectorsWritten[2]={0,0};
unsigned int	DxSectorsRead[2]={0,0};
unsigned char	SystemUptimeDiv=0;
unsigned int	SystemUptime=0;

unsigned 	DebugDiv=0;
//Functions
unsigned char	ShiftInP(void);				//Function for shifting in command and address with parity bit
							//from the controller. 0xFF - parity error
unsigned char	ShiftIn(void);				//Function for shifting in data from controller with no parity

void		ShiftOut(unsigned char ShiftByte);	//Function for shifting out data to controller

unsigned char	SpiSend(unsigned char SpiData);

/* Functions for write/read to/from flash memory
*  TrkNum - track number  (0-77 for DX drive)
*  SecNum - sector number (0-26 for DX drive)
*  DiskNum - disk number  (0,1 - DX drives)
*/

void		RomSetStatus(unsigned char RomStatus);
unsigned char	RomGetStatus(void);
void		RomEnWrite(void);
void		RomEraseBlock(unsigned long int EraseBlockAddr);
void		RomEraseImage(unsigned long int EraseBlockAddr);
unsigned char 	RomRead(unsigned char DiskNum, unsigned char TrkNum,unsigned char SecNum);	//Reads 128-byte sector from flash memory
unsigned char 	RomWrite(unsigned char DiskNum, unsigned char TrkNum,unsigned char SecNum);	//Writes 128-byte sector to flash memory
void		RomSectorRead(unsigned long int SectorReadAddr,unsigned char SectorReadBuffer);
void		RomSectorWrite(unsigned long int SectorWriteAddr,unsigned char SectorWriteBuffer);
void		RomCopyImage(unsigned long int ImageSourceAddr,unsigned long int ImageDestAddr);

void		ExitState(void);			//Function that exits current state because of reset signal or error

void		HexSend(unsigned char HexChar);
void		DecSend(unsigned int DecData,unsigned char DecPadding);

unsigned char	Xtransmit (unsigned char DriveNum);

#include "cli_dxemu.h"

// ProgramStart
int main()
{
	//INIT
	//port init
	//DX SET (NACH.UST.)  - input, pulled high
	DxSetPort|=(1<<DxSetPin);
	DxSetDdr&=~(1<<DxSetPin);

	//DX RUN (PUSK)  - input, pulled high
	DxRunPort|=(1<<DxRunPin);
	DxRunDdr&=~(1<<DxRunPin);

	//DX data in  - input, pulled high
	DxDiPort|=(1<<DxDiPin);
	DxDiDdr&=~(1<<DxDiPin);

	//DX 12bit - input, pulled high
	Dx12bitPort|=(1<<Dx12bitPin);
	Dx12bitDdr&=~(1<<Dx12bitPin);

	//DX data out pin - output, high (pulled high on bidir line in computer)
	DxDoPort|=(1<<DxDoPin);
	DxDoDdr|=(1<<DxDoPin);

	//DX IR (TREB.PEREDACHI).  - output, high
	DxIrPort|=(1<<DxIrPin);
	DxIrDdr|=(1<<DxIrPin);

	//DX DONE (ZAVERSHENO)  - output, high
	DxDonePort|=(1<<DxDonePin);
	DxDoneDdr|=(1<<DxDonePin);

	//DX OUTPUT (VYVOD)  - output, high
	DxOutPort|=(1<<DxOutPin);
	DxOutDdr|=(1<<DxOutPin);

	//DX ERROR (OSHIBKA)  - output, high
	DxErrPort|=(1<<DxErrPin);
	DxErrDdr|=(1<<DxErrPin);

	//DX SHIFT (SDVIG)  - output, high
	DxShftPort|=(1<<DxShftPin);
	DxShftDdr|=(1<<DxShftPin);


	//UART init
	UartTxDdr|=(1<<UartTxPin);	//UART Tx - OUT

	UartRxPort|=(1<<UartRxPin);	//UART Rx - IN, pulled high
	UartRxDdr&=~(1<<UartRxPin);
	UCSR0A=0b00000010;
	UCSR0B=0b11011000;	//Tx enabled, RX enabled
	UCSR0C=0b00000110;	//
	UBRR0H=0;
	UBRR0L=15;		//115200 8N1

	//SPI-mem init
	SpiCePort|=(1<<SpiCePin);	//SPI CE - OUT, init high
	SpiCeDdr|=(1<<SpiCePin);
	SpiMisoPort|=(1<<SpiMisoPin);
	SpiMisoDdr&=~(1<<SpiMisoPin);
	SpiMosiDdr|=(1<<SpiMosiPin);
	SpiSckDdr|=(1<<SpiSckPin);

	SPCR=0b01010000;	//mode0, fosc/2
	SPSR=0b00000001;	//SPI2X=1

	//TIMER1 init
	TCCR1A=0b00000000;	//Normal port operation, CTC mode
	TCCR1B=0b00001100;	//CTC mode,Fclk/256
	TCCR1C=0b00000000;

	OCR1A=5759;		//Period of 0,1s=14,7456MHz/256/5760

	TIMSK1=0b00000010;

	//INT init
	sei();

	//Activity LED 0 active high, out
	ActLedPort&=~(1<<ActLed0Pin);
	ActLedPort&=~(1<<ActLed1Pin);
	ActLedDdr|=(1<<ActLed0Pin);
	ActLedDdr|=(1<<ActLed1Pin);

	UartInit(115200);

	unsigned int TextPointer=&(StartupText[0]);
	while(1)
	{
		unsigned char TempChar=pgm_read_byte(TextPointer);
		if(TempChar==0)
			break;
		UartTxAddByte(TempChar);
		TextPointer++;
	}

	_delay_ms(100);
	CliInit();

	_delay_ms(1000);		//Startup delay
	DxDonePort&=~(1<<DxDonePin);	//Ready to receive command

	//ROM init - disable write protection
	RomSetStatus(0b00000000);

	//========== MAIN LOOP ==========

	while(1)
	{
		//TODO - make this process edge sensitive (INT)
		if ((DxRunIn&(1<<DxRunPin))==0)
		{
			if(DxCommand==NoCommand)
			{

				//Controller has initiated command transfer. Read command over SPI-DX.
				DxDonePort|=(1<<DxDonePin);	//Reply with command sequence started
				DxErrPort|=(1<<DxErrPin);	//Clears error signal
				DxTimeout=0;

				//Read command - shift in from controller
				unsigned char CommandTemp=ShiftInP();
				//TODO - parity test goes here
				DxDriveSelected=((CommandTemp>>4)&0x01);	//Saves selected drive
				DxCommand=((CommandTemp>>1)&7);			//Saves command
				if(SystemStatus&(1<<DebugOn))
				{
					DebugDiv=0;
					UartTxAddByte('C');
					UartTxAddByte(' ');
					UartTxAddByte(DxCommand+0x30);
					UartTxAddByte(' ');
				}
			}

			switch (DxCommand)
			{
				case 0:	//Fill buffer command
				{
					if(DxState==IdleState)		//Command received, initialise receive
					{
						DxState=FillBufferState;
						DxIrPort&=~(1<<DxIrPin);
						DxArrayPointer=0;
						if(SystemStatus&(1<<DebugVerbose))
						{
							UartSendString("\x0D\x0A");
							DebugDiv=0;
						}
					}
					else				//Receive 128 bytes from controller
					{
						DxArray[DxArrayPointer]=ShiftIn();
						if(SystemStatus&(1<<DebugVerbose))
						{
							HexSend(DxArray[DxArrayPointer]);
							UartTxAddByte(' ');
							DebugDiv++;
							if(DebugDiv>=8)
							{
								DebugDiv=0;
								UartSendString("\x0D\x0A");
							}
						}

						DxArrayPointer++;

						if(DxArrayPointer==128)
							ExitState();
						else
							DxIrPort&=~(1<<DxIrPin);
					}
					break;
				}

				case 1:	//Read buffer command
				{

					if(DxArrayPointer<128)
					{
						if(DxState==IdleState)
						{
						//TODO - merge with else
							DxState=ReadBufferState;
							DxOutPort&=~(1<<DxOutPin);
							_delay_us(10);
							ShiftOut(DxArray[0]);
							DxArrayPointer=1;
							DxIrPort&=~(1<<DxIrPin);
						}
						else
						{
							DxIrPort|=(1<<DxIrPin);
							ShiftOut(DxArray[DxArrayPointer]);
							DxArrayPointer++;
							DxIrPort&=~(1<<DxIrPin);
						}

					}
					else
					{
						DxIrPort|=(1<<DxIrPin);
						ExitState();
						if(SystemStatus&(1<<DebugVerbose))
						{
							for(DxArrayPointer=0;DxArrayPointer<128;DxArrayPointer++)
							{
								HexSend(DxArray[DxArrayPointer]);
								UartTxAddByte(' ');
								DebugDiv++;
								if(DebugDiv>=8)
								{
									DebugDiv=0;
									UartSendString("\x0D\x0A");
								}
							}
							UartSendString("\x0D\x0A");
						}

					}
					break;
				}

				case 2:	//Write sector to disk command
				case 3:	//Read sector from disk command
				case 6:	//Write marked sector to disk command
				{
					if(DxState==IdleState)
					{
						DxState=SecAddrWaitState;	//Receives sector address
						DxIrPort&=~(1<<DxIrPin);
						break;
					}
					if(DxState==SecAddrWaitState)
					{
						unsigned int	SectorTemp=ShiftInP();
						//TODO - parity test
						SecAddr=(SectorTemp-1);
						if (SecAddr>26)
						{
							DxErrPort&=~(1<<DxErrPin);
							ExitState();
							break;
							//TODO - add error variable
						}
						DxState=TrackAddrWaitState;
						DxIrPort&=~(1<<DxIrPin);
						break;
						//TODO - error if parity error

					}
					if(DxState==TrackAddrWaitState)
					{
						unsigned int	TrackTemp=ShiftInP();
						//TODO - parity test and exit
						TrackAddr=TrackTemp;
						if (TrackAddr>76)
						{
							DxErrPort&=~(1<<DxErrPin);
							ExitState();
							break;
							//TODO - add error variable
						}

						if(SystemStatus&(1<<DebugOn))
						{
							UartTxAddByte('D');
							UartTxAddByte(' ');
							DecSend(DxDriveSelected,0);
							UartTxAddByte('T');
							UartTxAddByte(' ');
							DecSend(TrackAddr,0);
							UartTxAddByte(' ');
							UartTxAddByte('S');
							UartTxAddByte(' ');
							DecSend(SecAddr,0);
						}

						switch (DxCommand)
						{
							case 2:
							case 6:
							{
								RomWrite(DxDriveSelected,TrackAddr,SecAddr);
								break;
							}

							case 3:
							{
								RomRead(DxDriveSelected,TrackAddr,SecAddr);
								break;
							}
						}
						ExitState();
					}
					break;
				}

				case 4:	//Unused
				{
					ExitState();
					break;
				}

				case 5:	//Read error and status register command
				{
					DxOutPort&=~(1<<DxOutPin);
					_delay_us(10);
					ShiftOut(DxStatusReg);
					ExitState();
					break;
				}

				case 7:	//Read disk error register command
				{
					DxOutPort&=~(1<<DxOutPin);
					_delay_us(10);
					ShiftOut(DxErrorReg);
					ExitState();
					break;
				}

				default:
				{
					ExitState();
					break;
				}
			}
		}
		//TODO - make reset edge sensitive (INT)
		if((DxSetIn&(1<<DxSetPin))==0)
		{
			//Fill buffer with drive 0 track 1 sector 0
			//TODO: make reset edge sensitive
			RomRead(0,1,0);
			DxDonePort|=(1<<DxDonePin);
			_delay_ms(100);
			DxOutPort&=~(1<<DxOutPin);
			_delay_us(10);
			ShiftOut(0b10000100);
			if(SystemStatus&(1<<DebugOn))
			{
				UartSendString("RST");
			}
			ExitState();
		}

		//CLI process call
		if((UartFlags&(1<<UartRxFifoEmpty))==0)
		{
		unsigned char RxTempLoop=UartRxGetByte();
		CliRoutine(RxTempLoop);
		}
	}
}

unsigned char	ShiftInP(void)		//Function for shifting in commands and addresses from controller
{
	DxIrPort|=(1<<DxIrPin);
	unsigned char ShiftData=0;
	unsigned char ParityBit=0;
	for(unsigned char ShiftCount=0;ShiftCount<8;ShiftCount++)
	{
		ShiftData=(ShiftData<<1);
		if((DxDiIn&(1<<DxDiPin))==0)
			{
			ShiftData++;	//If received 1, set data LSB to one
			ParityBit++;	//Increase parity counter on every received 1
			}
		DxShftPort&=~(1<<DxShftPin);	//Shift pulse
		_delay_us(1);
		DxShftPort|=(1<<DxShftPin);
		_delay_us(2);
	}
	if((DxDiIn&(1<<DxDiPin))==0)
		ParityBit++;		//Increase parity counter also on received parity 1
					//If there are no parity errors, parity LSB
					//should always be 1.
					//Parity is tested here
	if((ParityBit&1)==1)
	{
		return ShiftData;
	}
	else
	{
		UartSendString("PARITY ERROR");
		return 0xFF;		//Received command or track/sector address should never be
					//0xFF, so I can use this value as an error code.
	}
}

unsigned char	ShiftIn(void)		//Function for shifting in data from controller
{
	DxIrPort|=(1<<DxIrPin);		//Data transmission started, IR signal can be disabled
	unsigned char ShiftData=0;
	for(unsigned char ShiftCount=0;ShiftCount<8;ShiftCount++)
	{				//Shifts in 8 data bits from computer
		ShiftData=(ShiftData<<1);
		if((DxDiIn&(1<<DxDiPin))==0)
			ShiftData+=1;
		DxShftPort&=~(1<<DxShftPin);	//Shift pulse
		_delay_us(1);
		DxShftPort|=(1<<DxShftPin);
		_delay_us(2);
	}
	return ShiftData;		//Returns received data
}


void		ShiftOut(unsigned char ShiftByte)	//Function for shifting out data to controller
{
	for(unsigned char ShiftCount=0;ShiftCount<8;ShiftCount++)
	{						//Shifts out eight data bits
		if((ShiftByte&0b10000000)==0)
			DxDoPort|=(1<<DxDoPin);
		else
			DxDoPort&=~(1<<DxDoPin);
		ShiftByte=(ShiftByte<<1);
		_delay_us(1);
		DxShftPort&=~(1<<DxShftPin);
		_delay_us(1);
		DxShftPort|=(1<<DxShftPin);
		_delay_us(2);
	}
	DxDoPort|=(1<<DxDoPin);				//Data line - idle
}


unsigned char	SpiSend(unsigned char SpiData)		//Function for data receive/transmit to ROM over SPI
{
	SPDR=SpiData;					//Outputs data
	while((SPSR&0b10000000)==0);			//Waits for data to be shifted out
	unsigned char SpiTemp=SPDR;			//Reads received data
	return(SpiTemp);				//Returns received data
}


/*
* Data map in ROM:
000000-03FFFF:	DX0 disk
040000-07FFFF:	Temporary data blocks (sectors)
080000-0FFFFF:	DX1 disk
040000-07FFFF:	Temporary data blocks (Xmodem)
100000-13FFFF:	backup for DX0
180000-1BFFFF:	backup for DX1

DX disks populates only about half of 4MB assigned to each disk.
Flash memory can be only erased by 4KB blocks, so there's need
for temporary storage when one of 32 emulated sectors located in
flash memory block that is erased. So second half of DX0 disk is used
as a blocks for temporary storage while changing one sector. So:
040000-07FFFF:  64 temporary blocks

Also, temporary location is used for temporary saving  image
that's being received over serial line using Xmodem. After
successfully receiving full image, it's copied to desired
floppy area.
*/

void		RomSetStatus(unsigned char RomStatus)	//Function that sets flash memory status byte
{
	SpiCePort&=~(1<<SpiCePin);
	_delay_us(2);
	SpiSend(0x50);			//Enable write status command
	SpiCePort|=(1<<SpiCePin);
	_delay_us(2);

	SpiCePort&=~(1<<SpiCePin);
	_delay_us(2);
	SpiSend(0x01);			//Write status command
	SpiSend(RomStatus);		//Set status
	SpiCePort|=(1<<SpiCePin);
	_delay_us(2);
}

unsigned char	RomGetStatus(void)			//Function that reads flash memory status 
							//Used to determine if write is busy
{
	SpiCePort&=~(1<<SpiCePin);
	_delay_us(2);
	SpiSend(0x05);					//Read status command


	unsigned char StatTemp=SpiSend(0);		//Get status value
	SpiCePort|=(1<<SpiCePin);
	_delay_us(2);
	return StatTemp;				//Returns status value
}

void		RomEnWrite(void)			//Function enables flash memory write
							//Should be executed before erase or write
{
	SpiCePort&=~(1<<SpiCePin);
	_delay_us(2);
	SpiSend(0x06);					//Enable write command
	SpiCePort|=(1<<SpiCePin);
	_delay_us(2);
}
							//Erase block in flash memory.
void		RomEraseBlock(unsigned long int EraseBlockAddr)
{
	RomEnWrite();
	while(RomGetStatus()&0x01);			//Waits another write to complete
	SpiCePort&=~(1<<SpiCePin);
	_delay_us(2);
	SpiSend(0x20);					//Erase block command
	SpiSend(EraseBlockAddr>>16);
	SpiSend(EraseBlockAddr>>8);
	SpiSend(EraseBlockAddr);
	SpiCePort|=(1<<SpiCePin);
	_delay_us(2);
	while(RomGetStatus()&0x01);			//Waits for erase to complete
}

void		RomEraseImage(unsigned long int EraseBlockAddr)
{
	for(unsigned char EraseLoop=0;EraseLoop<64;EraseLoop++)
	{
        	RomEraseBlock(EraseBlockAddr);
		EraseBlockAddr+=0x1000;
	}
}

void RomSectorRead(unsigned long int SectorReadAddr,unsigned char SectorReadBuffer)
{
	//Read sector into buffer
	SpiCePort&=~(1<<SpiCePin);
	_delay_us(2);
	SpiSend(0x03);
	SpiSend(SectorReadAddr>>16);
	SpiSend(SectorReadAddr>>8);
	SpiSend(SectorReadAddr);
							//Reads one sector (128 bytes) info buffer
	for(unsigned char RomReadLoop=0;RomReadLoop<128;RomReadLoop++)
	{
		if(SectorReadBuffer==0)
			CopyArray[RomReadLoop]=SpiSend(0);	//Read from flash byte by byte
		else
			DxArray[RomReadLoop]=SpiSend(0);	//Read from flash byte by byte

	}
	SpiCePort|=(1<<SpiCePin);
	_delay_us(2);
}

void	RomSectorWrite(unsigned long int SectorWriteAddr,unsigned char SectorWriteBuffer)
{
	RomEnWrite();

	SpiCePort&=~(1<<SpiCePin);
	_delay_us(1);
	SpiSend(0xAD);				//AAI write command
	SpiSend(SectorWriteAddr>>16);
	SpiSend(SectorWriteAddr>>8);
	SpiSend(SectorWriteAddr);
	if(SectorWriteBuffer==0)
	{
		SpiSend(CopyArray[0]);
		SpiSend(CopyArray[1]);
	}
	else
	{
		SpiSend(DxArray[0]);
		SpiSend(DxArray[1]);
	}
	SpiCePort|=(1<<SpiCePin);
	_delay_us(1);
	while(RomGetStatus()&0x01);

	for(unsigned char RomProgLoop=1;RomProgLoop<64;RomProgLoop++)
	{
		SpiCePort&=~(1<<SpiCePin);
		_delay_us(1);
		SpiSend(0xAD);
		if(SectorWriteBuffer==0)
		{
			SpiSend(CopyArray[RomProgLoop*2]);
			SpiSend(CopyArray[(RomProgLoop*2)+1]);
		}
		else
		{
			SpiSend(DxArray[RomProgLoop*2]);
			SpiSend(DxArray[(RomProgLoop*2)+1]);
		}
		SpiCePort|=(1<<SpiCePin);
		_delay_us(1);
		while(RomGetStatus()&0x01);
	}
	SpiCePort&=~(1<<SpiCePin);
	_delay_us(1);
	SpiSend(0x04);				//Disable write command
	SpiCePort|=(1<<SpiCePin);
	_delay_us(1);

}

		//Function that copies floppy image between backup, working or temporary locations.
void		RomCopyImage(unsigned long int ImageSourceAddr,unsigned long int ImageDestAddr)
{
	RomEraseImage(ImageDestAddr);
	for(unsigned int CopyLoop=0;CopyLoop<2048;CopyLoop++)
	{
		RomSectorRead(ImageSourceAddr,0);
		RomSectorWrite(ImageDestAddr,0);
		ImageSourceAddr+=0x80;
		ImageDestAddr+=0x80;
	}
}


unsigned char 	RomRead(unsigned char DiskNum,unsigned char TrkNum,unsigned char SecNum)	//Reads 128-byte sector from flash memory
{
	if(DiskNum==0)
		ActLedPort|=(1<<ActLed0Pin);
	else
		ActLedPort|=(1<<ActLed1Pin);
	//Calculates start address of desired sector
        unsigned long int SecAddr=((TrkNum*26));
        SecAddr+=SecNum;
        SecAddr*=128;
	SecAddr+=(DiskNum*0x80000);

	RomSectorRead(SecAddr,1);

	ActLedPort&=~((1<<ActLed0Pin)|(1<<ActLed1Pin));
	DxSectorsRead[DiskNum]++;
	return 0;
}


void HexSend(unsigned char HexChar)			//Function for transmitting debug data in human readable form
{
	unsigned char HexTemp=(HexChar>>4);
	if(HexTemp>9)
		UartTxAddByte(HexTemp+55);
	else
		UartTxAddByte(HexTemp+0x30);

	HexTemp=(HexChar&0x0F);
	if(HexTemp>9)
		UartTxAddByte(HexTemp+55);
	else
		UartTxAddByte(HexTemp+0x30);
}
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

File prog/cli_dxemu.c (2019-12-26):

//TODO - change all \x0D\x0A to \r\n
//TODO - integer without a caast warning
unsigned char const CatText[] PROGMEM="                _\x0D\x0A                  \\ \\\x0D\x0A                   \\ \\\x0D\x0A                    | |\x0D\x0A     /\\---/\\ _.---._| |\x0D\x0A    / ^  ^  \\         \\\x0D\x0A    ( 0  0  )          ;\x0D\x0A     '=Y=_.'          ;\x0D\x0A      /     __;--._   \\\x0D\x0A     / _) ='     / /  /\x0D\x0A    / ;/ ;'     / / ;'\x0D\x0A   ( /( ;'    (_(__/\x0D\x0A\x0D\x0A>";
unsigned char const HelpText[] PROGMEM="\r\nCommands:\r\n? - help\r\nxs0 - send RX0 image over Xmodem\r\nxs1 - send RX1 image over Xmodem\r\nxr0 - receive RX0 image over Xmodem\r\nxr1 - receive RX1 image over Xmodem\r\nb0 - backup RX0 image\r\nb1 - backup RX1 image\r\nr0 - restore RX0 image from backup\r\nr1 - restore RX1 image from backup\r\nd0 - disable debug\r\nd1 - enable debug\r\nd2 - enable verbose debug\r\nv - show version\r\ns - statistics\r\n\r\n>";

//Command Line Interface functions

//CLI Init - nothing really to init, simply prints
//out that CLI is active and shows prompt
void    CliInit(void)
{
	UartSendString("\x0D\x0A-----\x0D\x0A");
	UartSendString("CLI started\x0D\x0A>");
}

//CLI routine - should be executed periodically.
//It reads characters received over serial line
//and executes commands
void    CliRoutine(unsigned char CliData)
{
	switch(CliData)
	{
		//If 0x0D received, it means that Enter button is presed
		//and command should be executed
		case 0x0D:
		{
			//If there's no command entered, nothing can be executed
			//so it simply prints out prompt
			if(CliBufferPointer==0)
			{
				UartSendString("\x0D\x0A");
				UartSendString(">");
			}
			else
			{
				//First entered letter determines command.
				//v - show version
				//x - xmodem file transfer
				//b - backup
				//r - restore
				//d - debug
				switch(CliBuffer[0])
				{

					//Version
					case 'v':
					case 'V':
					{
						//Reads serian number and bootloader version from flash
						//Reads firmware version from flash and prints all that is printable
						if(CliBufferPointer==1)
						{
							unsigned char	FlashData;
							UartSendString("\x0D\x0A");
							UartSendString("SN: ");
							for(unsigned char FlashLoop=0;FlashLoop<64;FlashLoop++)
							{
								FlashData=pgm_read_byte(0x7F40+FlashLoop);
								if(FlashData<0x7F)
									UartTxAddByte(FlashData);
							}
							UartSendString("\x0D\x0A");
							UartSendString("BL: ");
							for(unsigned char FlashLoop=0;FlashLoop<64;FlashLoop++)
							{
								FlashData=pgm_read_byte(0x7F00+FlashLoop);
								if(FlashData<0x7F)
									UartTxAddByte(FlashData);
							}
							UartSendString("\x0D\x0A");
							UartSendString("FW: ");
							for(unsigned char FlashLoop=0;FlashLoop<64;FlashLoop++)
							{
								FlashData=pgm_read_byte(0x7700+FlashLoop);
								if(FlashData<0x7F)
									UartTxAddByte(FlashData);
							}
							UartSendString("\x0D\x0A\x0D\x0A");
							UartSendString(">");
						}
						else
							UnknownCommand();
						break;
					}

					//Xmodem
					case 'x':
					case 'X':
					{
						unsigned char XmodemTransferStatus=0;
						#define		TransferInProcess	0
						#define		TransferSectorOk	1
						#define		TransferCompleted	2
						#define		TransferTimeout		3
						#define		TransferOutOfSync	4
						#define		TransferCrcFailed	5
						#define		TransferNoSoh		6
						#define		TransferTooLong		7
						#define		TransferTooShort	8
						#define		TransferExit		9
						#define		TransferCancelled	10
						#define		TransferTooManyRetries	11

						//Tests if command length with parameters is correct
						if(CliBufferPointer==3)
						{
							//Tests second symbol that determines Xmodem function
							//s - sends floppy image to computer
							//r - receives floppy image from computer
							switch(CliBuffer[1])
							{

								//Sending
								case 's':
								case 'S':
								{
									if((CliBuffer[2]<'0')|(CliBuffer[2]>'1'))
									{
										IncorrectDrive();
										break;
									}
									UartSendString("\x0D\x0A");
									UartSendString("Sending RX");
									UartTxAddByte(CliBuffer[2]);
									UartSendString(" image over Xmodem...");
									//Drive number - 3. character of the command.
									//Use only LSB, so there's only two possible drive numbers
									unsigned char	XDriveNumber=(CliBuffer[2]&1);
									unsigned char	XErrorCount=0;
									#define		XErrorMax	10
									#define		XTimeoutMax	300

									if(XDriveNumber==0)
										ActLedPort|=(1<<ActLed0Pin);
									else
										ActLedPort|=(1<<ActLed1Pin);

									unsigned int PacketNumber=1;
									unsigned char PacketCrc=0;
									unsigned long int SectorAddr=XDriveNumber;
									SectorAddr=(SectorAddr*0x80000);
									XmodemTransferStatus=TransferInProcess;
									XmodemTimeout=0;
									//Xmodem send loop
									while(1)
									{
										while(1)
										{
											unsigned char BuffTest=UartIsBufferEmpty();
											_delay_us(1);
											if(BuffTest==0)
											{
												unsigned char NakTest=UartRxGetByte();
												if(NakTest==0x15)
												{
													XErrorCount++;
													if(XErrorCount>=XErrorMax)
													{
														XmodemTransferStatus=TransferTooManyRetries;
													}
													break;
												}
												if(NakTest==0x03)
												{
													XmodemTransferStatus=TransferCancelled;
													break;
												}
												if(NakTest==0x06)
												{
													SectorAddr+=0x80;
													XErrorCount=0;
													XmodemTimeout=0;
													PacketNumber++;
													// 77 tracks, 26 sectors per track makes 2002 overall sectors
													if(PacketNumber==2003)
														XmodemTransferStatus=TransferCompleted;
													break;
												}
											}
											if(XmodemTimeout>=XTimeoutMax)
											{
												XmodemTransferStatus=TransferTimeout;
												break;
											}

										}

										if(XmodemTransferStatus>TransferInProcess)
											break;


										PacketCrc=0;			//re-initialises checksum variable
										RomSectorRead(SectorAddr,0);	//reads desired sector from ROM to buffer

										UartTxAddByte(0x01);		//Sends SOH - packet start
										UartTxAddByte(PacketNumber&0xFF);	//Sends packet number
										UartTxAddByte(0xFF-(PacketNumber&0xFF));
										//Sends 128 bytes - one sector stored in buffer
										for (unsigned char XByteLoop=0;XByteLoop<128;XByteLoop++)
										{
											UartTxAddByte(CopyArray[XByteLoop]);
											PacketCrc+=CopyArray[XByteLoop];	//Adds every byte to checksum
										}
										UartTxAddByte(PacketCrc);	//Sends checksum

									//TODO - make ASCII control code include?

									}
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

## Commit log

2019-04-21 error registers added, no tests yet
    [main.c]
2019-04-21 RT-11 tries to initialise disk, still DIR fails
    [main.c]
2019-04-22 minimal functionality, works with serious issues
    [main.c]
2019-05-01 faster AAI programming used, activity LED added
2019-05-05 lot of comments added, preparing for using interrupts
2019-05-08 Да, это то, что мне надо. Сколько цена за каждую?
2019-05-13 unfinished PCB added, working on parallel port connections
2019-06-18 Bootloader source folder added, at this time unmodified Arduino loader that's not compatible with my board.
    [dxemu_bootloader.c]
2019-06-27 almost finished PCB
2019-06-27 added empty schematics file
    [dxemu_v_1_0_(pcad2006).sch]
2019-07-06 schematics almost finished
    [dxemu_v_1_0_(pcad2006).sch]
2019-07-09 finished PCB and SCH added
    [dxemu_v_1_0_(pcad2006).sch]
2019-07-16 PCB finished, ordered, partial documentation added
2019-07-16 gerber files added
    [DXEMU_V_1_0.GBL, DXEMU_V_1_0.GBO, DXEMU_V_1_0.GBS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]
2019-07-16 schematics moved to documentation folder
2019-08-09 CAD folder added with isolation plastics drawing
    [dxemu_plastics.dxf]
2019-08-11 UART FIFO implementation started
2019-09-26 Xmodem transfer seems buggy, small improvements made
    [cli_dxemu.c]
2019-09-26 xmodem bug fixed, some mess cleaned up
    [cli_dxemu.c]
2019-09-30 PCB buglist added
2019-10-03 assembly drawing added, two small PCB bugs fixed
    [dxemu_plastics.dxf]
2019-10-03 assembly drawing fixed
2019-10-09 sch finished
    [dxemu_v_1_0_(pcad2006).sch]
2019-10-09 sch fixed
    [dxemu_v_1_0_(pcad2006).sch]
2019-10-19 Xmodem sending finihed with timeouts and error messages
    [cli_dxemu.c]
2019-12-17 Freezing on command 4 fixed, debug improved, cat function added
    [cli_dxemu.c, main.c]
2019-12-17 test commit, cat function crashes everything
    [cli_dxemu.c]
2019-12-17 should be tested on all boards
2019-12-26 program crashes, pushing for test purposes
    [cli_dxemu.c]
2019-12-26 RAM overflow fixed with moving strings from RAM to Flash memory
    [cli_dxemu.c, main.c]
2020-01-01 unexpected restarts, xmodem does not work on MAC with lsx
    [main.c]
